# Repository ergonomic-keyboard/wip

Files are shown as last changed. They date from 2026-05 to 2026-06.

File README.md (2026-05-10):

# Custom Keyboard Generator

A browser-based tool for designing custom split ergonomic keyboards. Tap your finger positions, preview in 3D, and get a complete bill of materials with purchase links.

## Quick Start

Launch both the keyboard wizard and the requirement tracker:

```bash
cd /home/a/git/git/keyboard/wip
fuser -k 8080/tcp 8099/tcp 2>/dev/null; python3 -m http.server 8080 & node req-tracker.js & wait
```

- Keyboard wizard: http://localhost:8080/wizard.html
- Requirement tracker: http://localhost:8099

## Keyboard Wizard

Open http://localhost:8080/wizard.html and follow the 4 steps:

1. **Tap finger positions** — place your left hand flat and tap 3 key positions per finger column (pinky through thumb)
2. **3D preview** — interactive 3D model with shadows, wooden frame enclosure, click-to-press keys, exploded view, and component labels
3. **Bill of materials** — full parts list with prices and purchase links, download design files as a ZIP
4. **Firmware & test** — generated ZMK shield files, keymap visualization, native_posix hardware emulation tests

## Requirement Tracker

Tracks PASS/FAIL/SKIP status for each requirement in `final_requirements.md`, per git commit.

```bash
node req-tracker.js
```

Open http://localhost:8099.

**Features:**
- Each requirement from `final_requirements.md` is shown with its full text
- Mark each requirement PASS, FAIL, or SKIP
- Click the comment button to add notes (e.g. what's wrong, how to fix it)
- Edit requirement text inline (click the text, edit, click away to save)
- Add new requirements with the "+ Add requirement" button
- Navigate between git commits using the arrows in the top-right
- When navigating to a commit with no status, it inherits PASS/FAIL/SKIP from the nearest reviewed commit (comments are per-commit and not inherited)

**Storage:**
- Status files are saved in `req-status/<commit-hash>.json`
- These files are inside the git repo — commit them to sync progress to GitHub
- Requirement edits are saved directly to `final_requirements.md`

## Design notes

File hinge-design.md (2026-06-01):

# Hinge Mechanism Design — 6 Configurations

> Two fold hinges × three butterfly joints = six selectable configurations.

---

## 1. Architecture Overview

The hinge assembly sits at the center edge of the keyboard (X = hingeX, between R and T keys). It provides two independent rotation axes that intersect at a single **pivot center** point:

- **Fold axis (Y):** horizontal, runs belly-to-screen. Rotates halves 0°–180° (flat→closed) and beyond to 270° (tented).
- **Butterfly axis (Z):** vertical, perpendicular to table. Rotates each half ±45° (swimming-stroke wing motion).

### The Angled-Bracket Solution (from mechanism_1.png)

The pivot center must be raised above the board's top surface to allow clean 180° fold-to-close without the inner edges of the two halves colliding:

```
Board stack thickness: T_FRAME = 4.8mm (Z_BOTTOM=0 to Z_SWITCH_PLATE_TOP=4.8)

If pivot is AT the top surface (Z=4.8mm):
  The bottom edge (Z=0) of one half sweeps a 4.8mm arc.
  At 180°, the bottom edges collide — they occupy the same point.

Solution: Raise pivot by PIVOT_OFFSET above Z_SWITCH_PLATE_TOP.
  PIVOT_OFFSET = 4.0mm (provides ~3.2mm clearance at worst angle)
  Pivot center Z = Z_SWITCH_PLATE_TOP + PIVOT_OFFSET = 8.8mm

Each half connects to the pivot via an angled bracket:
  Bracket angle: α = 15° above horizontal
  Bracket arm length: L = PIVOT_OFFSET / sin(α) = 4.0 / 0.259 ≈ 15.5mm
  Horizontal reach: L × cos(α) = 15.5 × 0.966 ≈ 15.0mm

The bracket extends from the board's inner edge (X = hingeX) outward
by 15mm to reach the raised pivot. Each half has one bracket.
Total gap between halves when flat ≈ 30mm.
```

### Component Nesting Order (Z axis, bottom to top)

```
    Z = 14.8mm   ─ Thumb nut / cam lever (clamping the butterfly joint)
    Z = 13.0mm   ─ Belleville or wave washer
    Z = 12.5mm   ─ Upper butterfly disc (attached to RIGHT bracket)
    Z = 10.0mm   ─ ── teeth mesh zone ──
    Z =  9.5mm   ─ Lower butterfly disc (attached to LEFT bracket)
    Z =  8.8mm   ─ PIVOT CENTER ← fold shaft passes through here along Y
    Z =  8.0mm   ─ Fold hinge body (PHA housing or bearing yoke)
    Z =  4.8mm   ─ Z_SWITCH_PLATE_TOP (board top surface)
    Z =  0.0mm   ─ Z_BOTTOM (table)
```

The fold shaft (Y axis) passes through the central bore of both butterfly discs.
The butterfly discs rotate around Z relative to each other (constrained by teeth).
The fold shaft rotates around Y (constrained by the fold hinge mechanism).

---

## 2. Fold Hinge A: Reell PHA 8mm Friction Positioning Hinge

### Specifications

| Parameter | Value |
|---|---|
| Shaft diameter | 8mm |
| Weight | 8g |
| Torque | 0.46 N·m (recommended; range 0.28–0.65) |
| Rotation | 360° continuous |
| Life | 50,000 cycles |
| Mounting | M2.5 flag-leaf screw holes |
| Body dims (est.) | 22 × 12 × 10mm (L×W×H) |

### How It Works

A wrap-spring clutch around the 8mm shaft creates constant, symmetric friction torque. The shaft rotates freely in either direction against controlled resistance. No gears, detents, or discrete stops — infinite holding positions. The flag leaf (flat mounting tab) bolts to one bracket; the shaft end inserts into a bearing seat on the other bracket.

### 3D Parts List

| # | Part | Geometry | Material | Dims (mm) |
|---|---|---|---|---|
| 1 | PHA body | Rounded box | Zinc (chrome mat) | 22×12×10 |
| 2 | PHA shaft | Cylinder along Y | Steel | Ø8 × 30 |
| 3 | Flag leaf | Thin box, 2 screw holes | Steel | 15×12×1.5 |
| 4 | Left bracket | L-shape bent at 15° | Stainless steel | 15×12×2 arm |
| 5 | Right bracket | L-shape bent at 15° | Stainless steel | 15×12×2 arm |
| 6 | M2.5 bolts ×4 | Cylinder + hex head | Steel | Ø2.5×6 |

### Weight Breakdown

| Component | Weight |
|---|---|
| PHA 8mm hinge | 8g |
| Brackets (2× SS) | 10g |
| Fasteners (4× M2.5) | 2g |
| **Subtotal (fold only)** | **20g** |

---

## 3. Fold Hinge B: Miniature Sealed-Bearing Pivot

### Specifications

| Parameter | Value |
|---|---|
| Pivot pin diameter | 4mm |
| Bearing | 2× MR84ZZ (4×8×3mm, sealed) |
| Rotation | 270° (limited by yoke slot) |
| Friction | Near-zero (ball bearing) |
| Mounting | Yoke bolts to right bracket; pin retained by E-clips |

### How It Works

A titanium (or stainless) 4mm pin runs through two MR84ZZ micro ball bearings pressed into the arms of a U-shaped yoke. The yoke is bolted to one half's bracket. The pin is retained by E-clips and bolted to the other half's bracket. The yoke's open slot spans 270° of arc, allowing flat→tent→closed rotation. Nearly frictionless — tenting angle is held entirely by cables.

### 3D Parts List

| # | Part | Geometry | Material | Dims (mm) |
|---|---|---|---|---|
| 1 | Pivot pin | Cylinder along Y | Titanium | Ø4 × 18 |
| 2 | MR84ZZ bearings ×2 | Torus (OD8, ID4, W3) | Chrome steel | Ø8×3 |
| 3 | Yoke | U-bracket | Stainless steel | 12×20×2 sheet |
| 4 | E-clips ×2 | Thin ring | Spring steel | Ø4 |
| 5 | Left bracket | L-shape bent at 15° | Stainless steel | 15×12×2 |
| 6 | Right bracket | L-shape bent at 15° | Stainless steel | 15×12×2 |
| 7 | M2.5 bolts ×4 | Cylinder + hex head | Steel | Ø2.5×6 |

### Weight Breakdown

| Component | Weight |
|---|---|
| Pivot pin (Ti) | 0.6g |
| 2× MR84ZZ | 2.6g |
| Yoke (SS) | 4g |
| Brackets (2× SS) | 10g |
| E-clips + bolts | 2g |
| **Subtotal (fold only)** | **19g** |

---

## 4. Butterfly Joint 1: Hirth Coupling (24 teeth)

### Specifications

| Parameter | Value |
|---|---|
| Outer diameter | 20mm |
| Inner bore | 9mm (clears PHA 8mm shaft + gap) |
| Tooth count | 24 |
| Angular resolution | 15° per tooth |
| Tooth profile | 60° V-groove, radially swept |
| Tooth height at OD | 2.3mm |
| Tooth height at ID | 0.7mm |
| Disc thickness | 5mm (3mm teeth + 2mm base) |
| Material | Hardened tool steel (HRC 58) |
| Weight per disc | 8g |
| Clamping | M4 thumb nut + Belleville washer |

### Tooth Geometry (computed)

```
n = 24, α = 60°
K = tan(π/2/24) / tan(60°/2) = tan(7.5°) / tan(30°) = 0.1317 / 0.5774 = 0.228
β = arcsin(0.228) = 13.17° (flank angle)

Height at r = 10mm (OD/2): h = 2 × 10 × tan(β) = 20 × 0.234 = 4.68mm
  → This is peak-to-valley. Tooth height (one side) ≈ 2.3mm

Height at r = 4.5mm (ID/2): h = 2 × 4.5 × tan(β) = 9 × 0.234 = 2.1mm
  → Tooth height at bore ≈ 1.05mm

Pitch at OD: π × 20 / 24 = 2.62mm per tooth
```

### 3D Parts

| # | Part | Geometry | Material |
|---|---|---|---|
| 1 | Upper Hirth disc | Cylinder + radial V-teeth on bottom face | Tool steel |
| 2 | Lower Hirth disc | Cylinder + radial V-teeth on top face | Tool steel |
| 3 | M4 clamping bolt | Cylinder through center bore | Steel |
| 4 | Belleville washer | Conical annular disc | Spring steel |
| 5 | M4 thumb nut | Knurled cylinder | Brass |

### Weight: 16g (pair) + 3g (bolt/washer/nut) = **19g**

---

## 5. Butterfly Joint 2: Curvic Coupling (36 teeth)

### Specifications

| Parameter | Value |
|---|---|
| Outer diameter | 22mm |
| Inner bore | 9mm |
| Tooth count | 36 |
| Angular resolution | 10° per tooth |
| Tooth profile | Circular arc (concave/convex mating pair) |
| Tooth height at OD | 1.8mm |
| Disc thickness | 4.5mm (3mm teeth + 1.5mm base) |
| Material | 17-4PH stainless steel (case-hardened) |
| Weight per disc | 7g |
| Clamping | M4 thumb nut + Belleville washer |

### Key Difference from Hirth

Curvic teeth are ground with a circular arc profile. One disc has concave teeth, the other convex. This provides:
- Self-centering under axial load
- Higher contact area (line contact vs point contact)
- Better wear characteristics

### 3D Parts

Same assembly as BJ1 but with arc-shaped teeth instead of V-grooves.

### Weight: 14g (pair) + 3g (hardware) = **17g**

---

## 6. Butterfly Joint 3: Serrated-Face Flange (72 teeth)

### Specifications

| Parameter | Value |
|---|---|
| Outer diameter | 18mm |
| Inner bore | 9mm |
| Tooth count | 72 |
| Angular resolution | 5° per tooth |
| Tooth profile | Shallow triangular, 90° included angle |
| Serration depth | 0.5mm |
| Disc thickness | 2.5mm (0.5mm teeth + 2mm base) |
| Material | 7075-T6 aluminum, hard anodized |
| Weight per disc | 3g |
| Clamping | Cam lever (quarter-turn quick-lock) |

### Key Differences

- Shallowest teeth (0.5mm vs 2.3mm Hirth) — lightest and thinnest
- Finest angular resolution (5° vs 15° Hirth)
- Aluminum instead of steel — adequate for keyboard forces
- Cam lever instead of thumb nut — faster one-handed operation

### 3D Parts

| # | Part | Geometry | Material |
|---|---|---|---|
| 1 | Upper serrated disc | Thin cylinder + fine radial teeth | Aluminum |
| 2 | Lower serrated disc | Thin cylinder + fine radial teeth | Aluminum |
| 3 | Cam lever | L-shape with eccentric | Steel/aluminum |
| 4 | Wave washer | Wavy annular ring | Spring steel |
| 5 | M4 bolt | Through center bore | Steel |

### Weight: 6g (pair) + 4g (lever/washer/bolt) = **10g**

---

## 7. Six Configuration Summary

| Config ID | Fold Hinge | Butterfly Joint | Total Weight | Butterfly Resolution |
|---|---|---|---|---|
| `pha-hirth` | PHA 8mm friction | Hirth 24T | 20 + 19 = **39g** | 15° |
| `pha-curvic` | PHA 8mm friction | Curvic 36T | 20 + 17 = **37g** | 10° |
| `pha-serrated` | PHA 8mm friction | Serrated 72T | 20 + 10 = **30g** | 5° |
| `bearing-hirth` | Bearing pivot | Hirth 24T | 19 + 19 = **38g** | 15° |
| `bearing-curvic` | Bearing pivot | Curvic 36T | 19 + 17 = **36g** | 10° |
| `bearing-serrated` | Bearing pivot | Serrated 72T | 19 + 10 = **29g** | 5° |

All under 50g (F01.2). All metal (F01.1).

---

## 8. Mechanical Connection Detail

### How the fold hinge and butterfly joint physically connect

The fold shaft (PHA 8mm shaft or 4mm bearing pin) runs along the Y axis, passing through the central bore of both butterfly discs. The assembly stacks vertically:

```
CROSS-SECTION at pivot center (looking along Y axis):

         Z (up)
         │
    ┌────┴────┐ Thumb nut (M4, knurled brass)
    └────┬────┘
    ┌────┴────┐ Belleville washer (spring steel)
    └────┬────┘
    ╔════╧════╗
    ║ UPPER   ║ Butterfly disc — bolted to RIGHT bracket
    ║  DISC   ║ via 2× M2 ears extending beyond OD
    ║ ╲╱╲╱╲╱  ║ Teeth face DOWN
    ╠═════════╣ ← TEETH MESH PLANE (Z ≈ pivot center)
    ║ ╱╲╱╲╱╲  ║ Teeth face UP
    ║  DISC   ║ Butterfly disc — bolted to LEFT bracket
    ║ LOWER   ║ via 2× M2 ears extending beyond OD
    ╚════╤════╝
         │
    ═════●═════ ← Fold shaft/pin (along Y axis, into page)
         │       PHA body or bearing yoke sits here
    ┌────┴────┐
    │ FOLD    │ PHA body (Hinge A) or Yoke (Hinge B)
    │ HINGE   │
    └─────────┘
```

### Bracket-to-Board Attachment

```
SIDE VIEW (one half, looking along X axis):

    Board inner edge
         │
         ▼
    ┌────────────── board top Z=4.8 ──────────
    │ ┌──┐
    │ │M2│ bracket bolt #1
    │ │.5│
    │ └──┘   Bracket (2mm SS, bent at 15°)
    │    ╲
    │     ╲  15° angle
    │      ╲
    │       ╲
    │        ●──── pivot center Z=8.8
    │       ╱ ╲
    │      ╱   Butterfly disc ear (M2 bolts)
    │     ╱
    │ ┌──┐
    │ │M2│ bracket bolt #2
    │ │.5│
    │ └──┘
    │
    └────────────── board bottom Z=0 ──────────
```

### The M4 clamping system

A single M4 bolt runs vertically through the center bore of both butterfly discs, through the fold shaft (which has a cross-drilled hole for it), and threads into the thumb nut on top. The Belleville washer provides spring-loaded axial preload. When the thumb nut is tightened, the discs are squeezed together, engaging their teeth. When loosened, the discs can be rotated to a new butterfly angle.

For the serrated flange (BJ3), the M4 bolt + thumb nut is replaced by a cam lever mechanism for faster one-handed operation.

---

## 9. Fold Animation Mechanics

### Pivot Point Change

The current code uses `hingeZ = Z_SWITCH_PLATE_TOP` (4.8mm). The new design raises this:

```javascript
const PIVOT_OFFSET = 4.0; // mm above board top surface
const hingeZ = Z_SWITCH_PLATE_TOP + PIVOT_OFFSET; // = 8.8mm
```

This changes the fold pivot for `applyFold()` and `applyButterfly()`.

### Bracket Animation

When folding, the angled brackets rotate with their respective halves. The fold hinge body/yoke stays at the pivot center (it's the bearing/pivot — it doesn't move). The butterfly discs rotate with their respective brackets.

In the 3D render, each bracket and its attached butterfly disc should be parented to the appropriate half (leftHalf or rightHalf). The fold shaft/pin and hinge body stay at the center (parented to the hinge group, which doesn't fold).

### What Stays Fixed vs What Moves

| Part | Fold behavior | Parent |
|---|---|---|
| Fold shaft/pin | Stays at center | hingeGroup (center) |
| PHA body / yoke | Stays at center | hingeGroup (center) |
| Left bracket | Rotates with left half | leftHalf |
| Right bracket | Rotates with right half | rightHalf |
| Lower butterfly disc | Rotates with left half | leftHalf (via bracket) |
| Upper butterfly disc | Rotates with right half | rightHalf (via bracket) |
| Thumb nut | Rotates with right half | rightHalf |
| M4 bolt | Stays at center | hingeGroup (center) |

---

## 10. Implementation Plan

### hardware-catalog.js
- Replace all old hinge entries with 2 fold hinges + 3 butterfly joints
- Add `butterflyJoint` as a new selection category
- 6 valid combinations = foldHinge × butterflyJoint
- Each entry has dims, weight, bom, and rendering metadata

### hardware-builders.js
- Delete old `buildBarrelHinge`, `buildPianoHinge`, `buildBallJointHinge`
- New builders:
  - `buildPHAHinge(dims, mats)` — PHA body + shaft + flag leaf
  - `buildBearingPivot(dims, mats)` — yoke + pin + bearings + E-clips
  - `buildBracketPair(dims, mats)` — left + right angled brackets
  - `buildHirthDiscs(dims, mats)` — upper + lower Hirth discs with teeth
  - `buildCurvicDiscs(dims, mats)` — upper + lower Curvic discs with arc teeth
  - `buildSerratedDiscs(dims, mats)` — upper + lower serrated discs
  - `buildClampAssembly(type, dims, mats)` — thumb nut or cam lever + washer + bolt
- Master `buildHardwareAssembly()` updated to compose fold + butterfly + brackets + clamp

### render3d.js
- Update `hingeZ` to include PIVOT_OFFSET
- Bracket geometry added to leftHalf/rightHalf (moves with fold)
- Center hinge parts stay in hingeGroup
- `applyFold()` and `applyButterfly()` use new pivot Z
- No change to fold/butterfly quaternion math (already correct)

### wizard.html
- Add `hw-butterfly` dropdown alongside `hw-hinge`
- Event listener to rebuild hardware on butterfly joint change

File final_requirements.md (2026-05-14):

# Final Requirements — Split Keyboard

All requirements use **shall** language and are deterministic and verifiable unless placed in the **Design Guidelines** section at the end.

---
Y runs positiveley along the columns (top to bottom of keyboard). Z is vertical (up from the table). ?X runs from left to right?

## 0. Requirements Tracker

**REQ-T01** — The requirements progress page shall contain buttons for: PASS, Assumed Pass, SKIP, Comment (icon), and Delete (which turns into Undo after clicking it).

**REQ-T02** — The end of each requirement type section (e.g. "4. Hardware — Structure", "2. Validation") shall include a + button to append a new requirement in that section at the end.

**REQ-T03** — The requirements tracker shall keep the numbers/scores of the self-attempts, self fails, user corrections as 2 columns right of the Delete button column. If the user hovers over the user fail, it will expand the requirement to display the notes for that requirement. As soon as the user does not hover over that user-fail count anymore, the note will disapear. The user shall be able to togle the notes on or off per requirement, and with a single binary toggle above the user-fail column for all requirements.

---

## 1. Layout & Input

**REQ-L01** — The system shall use the passhutk ergogen website to capture finger tap positions and generate a JSON layout for the split keyboard.

**REQ-L02** — The system shall convert the computed switch positions from the passhutk JSON (per REQ-L10.2) into a `config.yaml` compatible with ergogen.xyz.

**REQ-L02.1** — The conversion shall use the computed switch positions and the fitting algorithm metadata, not the raw tap coordinates directly.
**REQ-L03a** — The fitting algorithm shall deterministically compute switch center positions (x, y in mm), rotations (degrees), and sizes (mm) from the raw tap coordinates, the calibrated PPM, and the selected fitting algorithm per column.

**REQ-L03a.1** — Given identical inputs (same taps, same PPM, same algorithm selection), the computed switch positions, rotations, and sizes shall be bit-identical.

**REQ-L03b** — The ergogen config.yaml, when processed by the ergogen engine, shall produce switch positions within 0.05 mm and rotations within 0.05 degrees compared to the computed switch positions from REQ-L03a.

**REQ-L03b.1** — The ergogen output shall produce matching switch-edge-sizes compared to the computed switch positions from REQ-L03a.

**REQ-L03b.2** — This tolerance (0.05 mm position, 0.05 degrees rotation) is the single source of truth for the taps-to-ergogen conversion fidelity.

**REQ-L04** — Each column (pinky, ring, middle, index, inner, and thumb) shall have exactly 3 keys.

**REQ-L04.1** — The user shall provide at least 3 finger taps per column.

**REQ-L04.2** — Additional taps beyond 3 are permitted and encouraged as they are used by the passhutk layout tool to determine the key switch positions.

**REQ-L04a** — The keyboard shall have 6 columns per half (pinky, ring, middle, index, inner, thumb) x 3 keys per column = 18 keys per half, 36 keys total.

**REQ-L04a.1** — The BOM quantities for switches, keycaps, and hot-swap sockets (where applicable) shall match this count.

**REQ-L05** — Within a single finger column, all key rectangles shall be projected onto the column axis (fitted line) and rotated so their edges are perpendicular to that line.

**REQ-L05.1** — Keys within a column shall not rotate relative to each other.

**REQ-L06** — The thumb cluster shall be the only zone permitted to have a separate splay/rotation angle independent of the matrix columns.

**REQ-L07** — The user shall select a thumb fitting mode from three options.

**REQ-L07.1** — STRAIGHT mode: The 3 thumb key centers shall be projected onto a best-fit regression line through the thumb taps, using the same CoG-based placement algorithm as matrix columns (REQ-SF03).

**REQ-L07.1a** — In STRAIGHT mode, all 3 thumb keys shall share one rotation angle (the line angle).

**REQ-L07.1b** — STRAIGHT mode shall always produce a valid ergogen config.yaml (splay=0, spread=inter-key distance along line).

**REQ-L07.2** — ROTATED mode: The 3 thumb key centers shall be placed on a circular arc.

**REQ-L07.2a** — In ROTATED mode, the user shall specify (or the system shall fit from taps) a center point and radius R.

**REQ-L07.2b** — In ROTATED mode, keys shall be spaced at angular intervals on the arc.

**REQ-L07.2c** — In ROTATED mode, each key's rotation shall be tangent to the arc.

**REQ-L07.2d** — ROTATED mode shall always produce a valid ergogen config.yaml (uniform splay per column, inverse-solved origin offsets).

**REQ-L07.3** — ERGOGEN mode: The user shall directly enter ergogen thumb zone parameters (key.spread, key.splay, key.origin per column).

**REQ-L07.3a** — In ERGOGEN mode, these values shall be passed through to the config.yaml verbatim.

**REQ-L07a** — The selected thumb mode and its parameters shall be stored in the export JSON (per REQ-L10).

**REQ-L07a.1** — For STRAIGHT: the line angle shall be stored.

**REQ-L07a.2** — For ROTATED: the center, radius, and angular offsets shall be stored.

**REQ-L07a.3** — For ERGOGEN: the raw ergogen params shall be stored.

**REQ-L07b** — When the user switches thumb mode, the stage 1 canvas shall immediately recompute and redraw the 3 thumb switch positions using the newly selected algorithm.

**REQ-L07b.1** — The previous thumb taps shall be preserved (not cleared) when switching thumb mode.

**REQ-L08** — The system shall provide a "Tune Scale" calibration function: a modal displaying a reference line, user entry of measured physical width in mm, computing px/mm from CSS pixel width / entered mm.

**REQ-L08.1** — The calibrated value shall persist across sessions via localStorage.

**REQ-L09** — The ergopadToErgogen converter shall produce ergogen config parameters (spread, stagger, splay, padding, origin).

**REQ-L09.1** — The produced parameters, when processed by ergogen's placement algorithm, shall reconstruct the computed switch positions from REQ-L03a within the tolerance of REQ-L03b.

**REQ-L09.2** — The converter shall simulate ergogen's cumulative rotation stack.

**REQ-L09.3** — The converter shall inverse-solve for world-space zone_anchor positions.

**REQ-L09.4** — For the thumb zone, the converter shall use the algorithm-specific parameter derivation corresponding to the selected thumb mode (REQ-L07).
**REQ-L10** — The user shall be able to export and reload layout data as JSON.

**REQ-L10.1** — The export shall include raw tap coordinates per column (as `{x, y}` arrays).

**REQ-L10.2** — The export shall include computed switch positions per key: center (x, y) in mm, rotation in degrees, and switch size (width, height) in mm.

**REQ-L10.3** — The export shall include the fitting algorithm used per column: `regression-line` for matrix columns; `STRAIGHT`, `ROTATED`, or `ERGOGEN` for the thumb column, plus the algorithm-specific parameters (per REQ-L07a).

**REQ-L10.4** — The export shall include `calibratedPPM`, `canvasWidth`, `canvasHeight`.

**REQ-L10.5** — Loading shall scale raw tap positions correctly if canvas dimensions differ from the original.

**REQ-L10.6** — After loading, the system shall recompute switch positions from the stored taps and algorithm, and verify they match the stored computed positions (within floating-point tolerance).

**REQ-L11** — In the first screen where the finger taps are added the user shall be able to zoom in and out the key switches using 2 keyboard buttons/shortcuts that do not interfere with the normal browser/rest of the website.

**REQ-L11.1** — The scale tuning number shall change on a 1:1 ratio with the zoomlevel if it was specified earlier.

---

## 2. Validation

**REQ-V01a** — (Boundary 1 — taps to computed switches) The system shall verify that the fitting algorithm (per REQ-L03a) produces deterministic switch positions from the stored raw taps.

**REQ-V01a.1** — On JSON reload, the recomputed switch positions shall match the stored computed positions within floating-point tolerance (< 1e-6 mm).

**REQ-V01a.2** — If they differ, the system shall flag a fitting algorithm inconsistency error.

**REQ-V01b** — (Boundary 2 — computed switches to ergogen output) For each key, the distance between the computed switch position (from REQ-L03a) and the ergogen-generated position (from the config.yaml processed by ergogen) shall be less than the tolerance defined in REQ-L03b (0.05 mm).

**REQ-V01b.1** — Rotation shall match within 0.05 degrees.

**REQ-V01b.2** — If exceeded, the system shall flag the specific key with its position and rotation delta and throw an error.

**REQ-V02** — The relative arrangement of keys (center-to-center distances and directions between adjacent keys) shall be preserved between the computed switch positions and the ergogen output.

**REQ-V02.1** — The system shall detect if ergogen reorders, collapses, or distorts spatial relationships.

**REQ-V03** — No two switches shall occupy the same position.

**REQ-V03.1** — The center-to-center distance between every pair of keys shall exceed the switch housing width.

**REQ-V03.2** — This check shall apply both within each column and across columns.

**REQ-V04** — Validation shall recompute every time a finger tap is added or removed, without requiring navigation to a separate page.

**REQ-V05** — Validation errors shall be displayed directly on the page 1 canvas, overlaid on the affected key positions, using color-coded indicators (red for invalid, green for valid).

**REQ-V05.1** — A human-readable summary message shall be displayed below the toolbar.

**REQ-V06** — If validation detects overlapping switches or position mismatches exceeding the threshold, the Next button to page 2 shall be disabled.

**REQ-V06.1** — The error shall be displayed prominently.

---

## 3. Hardware — Switches & Keys

**REQ-H01** — The keyboard shall use Cherry MX ULP switches (ref: keeb.supply/products/cherry-mx-ulp).

**REQ-H02** — Soldering shall not be required for keyboard assembly, with the sole exception of Cherry MX ULP switches, which are SMD-mount and require soldering to the PCB.

**REQ-H02.1** — All other electrical connections (MCU, battery connector, USB-C) shall use solderless methods (hot-swap sockets, press-fit, pin headers, or similar).

**REQ-H03** — Each keycap in the 3D render and final product shall display the selected keyboard layout, e.g. QWERTY or Dvorak letter or symbol (Space, Tab, Backspace, Enter, etc.).

**REQ-H03.1** — A keycap legend set or sticker overlay sheet shall be included in the BOM.

---

## 4. Hardware — Structure

**REQ-S01** — The keyboard shall consist of two separate, independent halves.

**REQ-S02** — The board outline shall be smoothed from the raw ergogen staircase output.

**REQ-S02.1** — Index finger side: straight edge.

**REQ-S02.2** — Top edge: arc with radius determined by the angle between index and pinky columns.

**REQ-S02.3** — Pinky side: straight edge.

**REQ-S02.4** — Bottom edge: smaller arc.

**REQ-S02.5** — Thumb cluster: 8-12 mm fillet/border around thumb keys.

**REQ-S02.6** — Perimeter fillet shall be at least 8 mm.

**REQ-S03** — The board outline, switch plate, and wooden frame shall extend to cover all thumb keys.

**REQ-S03.1** — The thumb cluster shall not be a floating island; it shall be structurally connected to the main matrix area.

**REQ-S04** — The frame material shall be 2 mm thick bamboo plywood (Z-axis material thickness).

**REQ-S04.1** — The frame shall be two-part milled construction (bottom backbone + top bezel).

**REQ-S05** — The frame wall width (XY-plane border around the PCB/plate) shall be at least 4 mm.

**REQ-S06** — Fasteners shall be M2 heat-set brass threaded inserts (pressed into the frame from the bottom) paired with M2 countersunk flat-head bolts from the top.

**REQ-S06.1** — Bolt heads shall sit flush with the surface.

**REQ-S07** — Each half shall have at least 5 mounting points placed according to REQ-S07.1 through REQ-S07.5. The positions below in S07.1 to S07.5 are described for the left half, these nut and bolt coordinates are to be mirrored to the right half (acrross the middle axis from the user belly to the screen).
**REQ-S07.1** — Looking at the keyboard from the user, at the left half, with closest to the user as "bottom" and closest to screen as "top". One mounting point **on the diagnonal switch line (outside switch) through the top-left corner of the Y key, with the center of the nut on the diagonal of the switch**.  The bolt center shall be ≤ 10 mm from that corner. The bolt shall not overlap any switch footprint.
**REQ-S07.2** — Looking at the keyboard from the user, at the left half, with closest to the user as "bottom" and closest to screen as "top".  One mounting point **on the diagonal line (outside switch) through bottom-left corner of the N key**. The bolt center shall be ≤ 10 mm from that corner.
**REQ-S07.3** — Looking at the keyboard from the user, at the left half, with closest to the user as "bottom" and closest to screen as "top".  One mounting point bolt shall be on the **key diagonal line  (outside switch) through the top right corner of P switch** The bolt center shall be ≤ 10 mm from that corner.
**REQ-S07.4** — Looking at the keyboard from the user, at the left half, with closest to the user as "bottom" and closest to screen as "top". One mounting point bolt shall be on the **key diagonal line (outside switch) through the top-right corner of the outermost thumb key** (the thumb key farthest from the center/hinge). The bolt center shall be ≤ 10 mm from that corner.
**REQ-S07.5** — Looking at the keyboard from the user, at the left half, with closest to the user as "bottom" and closest to screen as "top". One mounting point bolt shall be on the **key diagonal line (outside switch) through the bottom-right corner of the outermost thumb key** (the thumb key farthest from the center/hinge). The bolt center shall be ≤ 10 mm from that corner.
**REQ-S07a** — Each mounting bolt shall pass through the top frame bezel and clamp through all intermediate layers (switch plate, cork, PCB, cork) into a heat-set brass insert in the bottom frame backbone.

**REQ-S07a.1** — All intermediate layers (switch plate, cork gaskets, PCB, bottom plate) shall have clearance holes at each mounting point.

**REQ-S07a.2** — The bolt-insert joint shall sandwich the full stack between the two frame pieces.

**REQ-S08** — The base layer stack (excluding cork gaskets, frame bezel, and keycaps) shall be: Bottom plate (bamboo) 2.0 mm (per REQ-S04), PCB (FR-4) 0.8 mm (standard 2-layer), Switch plate (bamboo or FR-4) 1.0 mm. Base total: 3.8 mm.

**REQ-S08.1** — The actual layer thicknesses shall be verified against the Cherry ULP switch datasheet and nice!nano PCB clearance requirements.

**REQ-S08.2** — If the datasheet requires different thicknesses, these values shall be updated and REQ-S09 recalculated accordingly.

**REQ-S08a** — A 0.5 mm natural cork gasket sheet shall be placed between the bottom plate and PCB, and between the PCB and switch plate.

**REQ-S08a.1** — Total stack height increase from cork shall be 1.0 mm.

**REQ-S09** — The overall keyboard thickness shall be minimized within the requirement-compliant design space.

**REQ-S09.1** — The total stack height shall not exceed 4.8 mm (3.8 mm base per REQ-S08 + 1.0 mm cork per REQ-S08a), excluding the frame bezel and keycaps.

**REQ-S10** — A battery area shall be designated on the PCB (under/beside the MCU, or along the thumb padding space in slender form factors).

**REQ-S10.1** — The design shall accommodate the battery without increasing the overall board width beyond what is required by the key layout.

**REQ-S10.2** — If the battery exceeds the available stack clearance, the bottom plate shall be locally milled thinner (cutout/recess) at the battery location to house it within the REQ-S09 stack height.

**REQ-S11** — A battery connector footprint shall be present on the PCB.

**REQ-S11.1** — Physical clearance shall be verified (bottom plate cutout or recess if needed).

**REQ-S12** — The key positions and cutout locations in the switch plate shall use expanded key padding (`px + 4` for board outline, `px + 8` for frame) to produce a smooth, continuous perimeter around all keys including the thumb cluster.

---

## 5. Hardware — Hinge & Folding

**REQ-F01** — The folding mechanism shall connect the two halves at the center (approximately between the R and T key positions).

**REQ-F01.1** — It shall be made of metal.

**REQ-F01.2** — It shall weigh at most 50 grams total.

**REQ-F01a** — The mechanism shall support two independent rotation axes.

**REQ-F01a.1** — Fold axis (horizontal, running from user belly toward screen): The two halves shall fold from flat on the table (0 degrees) to fully tented (at most 90 degrees).

**REQ-F01a.2** — Butterfly axis (vertical, perpendicular to the table surface): When flat on the table, the two halves shall rotate forward and backward like wings (toward/away from the screen) up to approximately 45 degrees from the centerline.

**REQ-F01b** — The butterfly rotation range (up to ~45 degrees) may be limited at certain fold angles due to geometric constraints (e.g., thumb pads colliding).

**REQ-F01b.1** — The 3D render shall enforce these collision limits per REQ-R07.

**REQ-F01c** — The keyboard shall fold fully closed for transport.

**REQ-F01c.1** — When folded closed, the keycap surfaces shall face each other (inward fold).

**REQ-F01c.2** — If a single mechanism cannot provide both the fold/butterfly range (REQ-F01a) and fold-to-close, the two connecting poles to the hinge shall be disconnectable (e.g., via magnetic breakaway or quick-release).

**REQ-F01c.3** — In that case, 2 or 3 magnets embedded in the keyboard wood frame shall hold the two halves closed.

**REQ-F01d** — The tenting angle shall be primarily determined and held by the cable turnbuckle settings (REQ-F09).

**REQ-F01d.1** — The hinge may optionally include a friction lock or thumb nut for additional rigidity on uneven/unstable surfaces.

**REQ-F01d.2** — If included, it shall not be required for normal desk use.

**REQ-F05** — Two horizontal cables shall connect the two halves of the keyboard on the bottom plate of the keyboard: one across the top row (approximately Q to P), one across the bottom row (approximately Z to M).

**REQ-F05.1** — These cables shall prevent the keyboard from collapsing under gravity/key press force.

**REQ-F05.2** — The cable closest to the user shall be attached below the left half of the keyboard board at the coordinate of the bottom right corner of the N switch.
**REQ-F05.3** — The cable closest to the user shall be attached below the right half of the keyboard at the coordinate of the bottom left corner of the Z switch.

**REQ-F05.4** — The cable furthest away from the user shall be attached below the left half of the keyboard board at the coordinate of the bottom right corner of the Y switch.

**REQ-F05.5** — The cable furthest away from the user shall be attached below the left half of the keyboard board at the coordinate of the bottom left corner of the Q switch.

**REQ-F05.6** — The cables will be attached on the left side using a nut with a ring eye as had through which the cable will pass. its bolt will be sinked into the cork and wooden backplate.

**REQ-F05.7** — The cables will be attached on the right side of the keyboard using magnetic attachment that clicks into place by moving the two sides close into each other like two hooks grappling into each other, such that the tension on the cable is transferred through the hook contacts, but that the  hooks staying hooked into each other is done by the magnet. (a cone and cone hole would prevent side slipping in any direction, a magnet would prevent disconnect at random wiggling/slight moments of movement where the tension on the cable may be reduced.
Alternatively Cables shall use quick-release clevis pins with spring-loaded ball detent for one-handed press-button detach. In that case Clevis brackets shall be recessed into the frame edge.
**REQ-F07** — The quick-release clevis pins with spring-loaded ball detent shall be positioned such that when the keyboard is folded closed, it will be on a flat surface on the backside of the board, and not at the edge of the keyboard.

**REQ-F08** — When detached, the cables shall wrap around the closed keyboard to keep it shut (like a rope around a diary).

**REQ-F08.1** — Two elastic bands shall secure the cables around the closed keyboard regardless of turnbuckle position, so the user does not need to adjust turnbuckle length each time the keyboard is folded.

**REQ-F09** — The cables shall include turnbuckles for adjustable tension/length, which controls the tenting angle and the butterfly wing rotation around the vertical axis.

---

## 6. Electronics & Connectivity

**REQ-E01** — The keyboard shall use the nice!nano wireless MCU.

**REQ-E02** — The keyboard shall support the following connectivity modes.

**REQ-E02.1** — Both halves communicate with each other over Bluetooth. One half connects to the laptop via USB-C; the other half syncs wirelessly to the first.

**REQ-E02.2** — Both halves connected directly to a laptop via USB-C (each half operates as an independent USB HID device).

**REQ-E02.3** — Fully wireless operation over Bluetooth (both halves to laptop, half-to-half over Bluetooth).

**REQ-E02.4** — In wired modes, Bluetooth shall be completely disableable via firmware configuration.

**REQ-E02.5** — Half-to-half communication shall use Bluetooth (not wired USB-C between halves). A non-wireless MCU option is out of scope.

**REQ-E03** — Each half shall have one USB-C port for charging and/or data.

**REQ-E04** — Two 301230 LiPo batteries (one per half) shall be included in the BOM.

**REQ-E04.1** — Battery placement shall be visible in assembly.scad.

**REQ-E04.2** — The battery connection to the PC will be included in the rendering.

**REQ-E05** — Keyboard firmware shall be available and functional for the nice!nano MCU (e.g., ZMK or equivalent).

---

## 7. Bill of Materials & Sourcing

**REQ-B01** — A complete Bill of Materials shall be produced, listing every component required to build the keyboard.

**REQ-B02** — Each BOM item shall include a link to an online supplier and the price per element.

**REQ-B03** — The BOM shall include the following components:

**REQ-B03.1** — Cork gasket sheets.

**REQ-B03.2** — Bamboo plywood sheets.

**REQ-B03.3** — M2 heat-set brass inserts.

**REQ-B03.4** — M2 countersunk flat-head bolts.

**REQ-B03.5** — Quick-release clevis pins.

**REQ-B03.6** — Turnbuckle cable assemblies.

**REQ-B03.7** — Elastic bands.

**REQ-B03.8** — Hinge mechanism (metal).

**REQ-B03.9** — Magnets for hinge pole disconnect and/or frame closure (per REQ-F01c).

**REQ-B03.10** — Cherry ULP switches.

**REQ-B03.11** — Keycaps (with legends or sticker sheet).

**REQ-B03.12** — nice!nano MCUs.

**REQ-B03.13** — 301230 LiPo batteries.

**REQ-B03.14** — USB-C connectors.

---

## 8. Assembly

**REQ-A01** — All bolts and inserts required for assembly shall be specified in the BOM with their positions documented.

**REQ-A01.1** — No screws shall be used; the design shall use only M2 bolts with heat-set brass inserts (per REQ-S06).

**REQ-A01.2** — There will be one nut and bolt in the bottom left corner, with the outer edge of the bolt 0.5 cm out of the edge (so the center of the nut will be 0.5 cm + nutradius from the edge). The nut will nut be at the position of a switch (again 0.5 cm away from switch.)
There will be another nut left above the thumb (as low as possible but still above.

If the angle between the inner column and the thumb column is larger than 10 degrees, then there will be another nut left below the outer inner colum. Otherwise it will be above the outer most switch of the inner column (between the switch and the edge).

Another screw will be in the top right corner.
Another screw will be in the bottom left corner.
**REQ-A02** — Files required for CNC-cutting/laser-cutting the wood frame pieces shall be generated and included in the project output.

**REQ-A03** — A builder's guide (`grandma_builder.md`) shall be produced containing only the sequential steps required for a non-technical person to assemble the keyboard from the kit.

---

## 9. 3D Render & Visualization

**REQ-R01** — The system shall produce an interactive 3D viewer (not just static PNG renders).

**REQ-R01.1** — The user shall be able to orbit, zoom, and pan.

**REQ-R01.2** — The user shall see a small legend with the keyboard navigation shortcuts in the top right of the screen.

**REQ-R01.3** — Ensure if the user wants to see component labels that it uses the diagonal line to top right followed by horizontal line towards its label, if the render is moved, resort the labels to prevent line crossings. Allow togling them off, e.g. if nuts are 7 nuts, show 7 labels, but allow one to toglle off specific nut lable,s or just the group nut.

**REQ-R02** — The 3D model shall update automatically when the input config changes (i.e., `generate.sh` produces a viewable 3D file).

**REQ-R03** — The 3D model shall show all components listed in REQ-R03.1–R03.12.

**REQ-R03.1** — The 3D model shall render the bamboo bottom plate.

**REQ-R03.2** — The 3D model shall render the cork gaskets.

**REQ-R03.3** — The 3D model shall render the FR-4 PCB.

**REQ-R03.4** — The 3D model shall render the switch plate.

**REQ-R03.5** — The 3D model shall render the wooden frame surround.

**REQ-R03.6** — The 3D model shall render the keycaps.

**REQ-R03.7** — The 3D model shall render the nice!nano MCU.

**REQ-R03.8** — The 3D model shall render the USB-C ports.

**REQ-R03.9** — The 3D model shall render the batteries.

**REQ-R03.10** — The 3D model shall render the hinge.

**REQ-R03.11** — The 3D model shall render the cables.

**REQ-R03.12** — The 3D model shall render the fasteners.

**REQ-R04** — An exploded view shall be togglable.

**REQ-R04.1** — In exploded view, all layers (bottom plate, cork, PCB, switch plate, frame) shall be distinguishable by material and labeled.

**REQ-R05** — Keycaps shall respond to click with a press animation.

**REQ-R06** — The center joint/hinge shall visually articulate when the fold angle changes.

**REQ-R06.1** — All hinge sub-components shall rotate/translate to match the fold angle.

**REQ-R06.2** — The specific sub-components rendered shall match the final hinge mechanism selected per REQ-F01.

**REQ-R07** — The butterfly wing rotation slider shall be available and its range shall be restricted by not allowing overlap/collision between any components (of the 2 sides, nor folding mechanism) depending on the fold slider setting.

**REQ-R07.1** — The fold slider shall always have full range.

**REQ-R07.2** — If a fold angle is selected at which the butterfly wing rotation slider constraints are violated, the butterfly wing rotation slider shall return to the nearest valid constrained (maximum) angle in degrees.

**REQ-R08** — The 3D render shall provide a fold slider covering the full range from flat (0 degrees) through tented (up to 90 degrees) through to fully closed (180 degrees).

**REQ-R08.1** — If the hinge mechanism requires disconnection to fold closed (per REQ-F01c), the render shall animate the disconnect (poles separating, magnets engaging) at the appropriate angle.

**REQ-R08.2** — Both halves shall remain fully visible and correctly positioned at all angles.

**REQ-R08.3** — No half shall disappear, clip through the ground plane, or produce visual artifacts.

**REQ-R08.4** — The pivot point shall be the hinge center axis.

**REQ-R09** — Cables shall visually connect to their keyboard edge attachment points.

**REQ-R09.1** — When folding, cables shall animate their release at the quick-release clevis pins and wrap around the other side.

**REQ-R10** — The nice!nano USB-C ports shall be rendered as chrome/metallic connectors with a dark opening, identifiable as USB-C at a glance.

**REQ-R11** — Keycap and switch positions in the 3D render shall be exactly aligned with switch plate cutouts.

**REQ-R11.1** — The coordinate offset shall be computed from the config.yaml directly, not from any generated svgs.

**REQ-R12** — Key legends shall be rendered as flat plane meshes on top of keycaps using canvas textures, with correct rotation matching key orientation.

**REQ-R13** — The bamboo/wood material shall use a pronounced normal map for surface relief and appropriate roughness/metalness PBR values.

**REQ-R13.1** — Visible grain lines, growth rings, node bands, tonal variation, and fiber detail shall be present.

**REQ-R14** — Fold direction in the 3D render shall match REQ-F01c (inward fold, keycap surfaces face each other when folded).

**REQ-R15** — No render clipping shall occur during fold at any angle.

**REQ-R15.1** — Clipping planes shall rotate with their respective halves.

**REQ-R16** — The 3D render shall visually reflect REQ-S03: the thumb cluster shall appear connected to the main body in all views (not as a floating island).

**REQ-R17** — You shall show the key switch outlines from the 1.Finger Positions as the highest layer in purple at 3 mm above the highest point of the board. (Don't edit them or anything, just a raw coordinate and rotational copy paste).

**REQ-R18** — You shall show the angle in degrees between the inner column line and the thumb column line in case the Thumb STRAIGHT option is shown. Also in purple (with a circular arrow between the two lines.)

**REQ-R19** — You shall render the board from a point of view like the user sees it when the user starts typing, so left is the left thumb pad (the left hand is also entered in stage 1 Figure Positions with the pinky column left and the left thumb in the BOTTOM right). So the thumbs are closer to the user than the other columns (NOT FURTHER AWAY).

**REQ-R20** — The render shall show the full fold to 0 degrees to 180 degrees flat on the table, to 270 degrees tilted.

**REQ-R21** — The render shall show the full fold to 0 degrees to 45 degrees butterfly as optional.

**REQ-R21.1** — You shall limit that degree based on the two halves bump into each other constraint at any given integer folding angle.

**REQ-R21.2** — The butterfly folds forward, away from user, toward screen. (horizontal line/as it is now is the normal/0 degrees.)

**REQ-R21.3** — In the GUI clearly indicate the limitation based on the fold angle if there is any limitation.

**REQ-R22** — ~~SUPERSEDED by REQ-R30.~~ *(Original: MCU on PCB top surface at half center.)*

**REQ-R23** — ~~SUPERSEDED by REQ-R33, REQ-R36.~~ *(Original: Battery between bottom plate and PCB with recess.)*

**REQ-R24** — ~~SUPERSEDED by REQ-R32, REQ-R34.~~ *(Original: USB-C at outer board edge as separate component.)*

**REQ-R25** — ~~SUPERSEDED by REQ-R30, REQ-R31, REQ-R32.~~ *(Original: Positions computed from bbox.)*

**REQ-R26** — The 3D render shall provide individual binary visibility toggles for each hardware layer.

**REQ-R26.1** — Keycaps toggle: Keycap meshes + key legends, default ON.

**REQ-R26.2** — Switch Plate toggle: Switch plate + switch housings/stems, default ON.

**REQ-R26.3** — Cork Upper toggle: Upper cork gasket, default ON.

**REQ-R26.4** — PCB toggle: PCB + MCU + USB-C + diodes + solder pads, default ON.

**REQ-R26.5** — Cork Lower toggle: Lower cork gasket + battery, default ON.

**REQ-R26.6** — Bottom Plate toggle: Bottom plate + battery recess, default ON.

**REQ-R26.7** — Each toggle shall independently show/hide that layer's meshes without affecting any other layer.

**REQ-R27** — Layer toggles shall work in both normal (assembled) view and exploded view.

**REQ-R27.1** — Toggling a layer off shall hide its meshes in whichever view mode is active.

**REQ-R27.2** — The exploded view separation and the layer toggles shall be independent controls.

**REQ-R28** — When a layer is toggled off, its exploded-view label (if any) shall also be hidden.

**REQ-R28.1** — Toggling the layer back on shall restore the label (if exploded view labels are enabled).

**REQ-R29** — The layer toggle controls shall be rendered as a row of labeled checkboxes (all checked by default), positioned near the existing fold/butterfly sliders in the 3D view toolbar.

**REQ-R29.1** — Each checkbox shall be labeled with its layer name.

**REQ-R30** — The nice!nano MCU shall be mounted on the underside of the PCB (components facing downward, toward the bottom plate).

**REQ-R30.1** — Its Z position shall place the MCU PCB flush against the underside of the main PCB at `Z_PCB`.

**REQ-R30.2** — The MCU's tallest component (USB-C connector, ~3.26mm) faces downward into a milled pocket in the bottom plate.

**REQ-R30.3** — The ergogen config shall include a back-side (`B.Cu`) footprint for the nice!nano, or the KiCad PCB file shall be post-processed to flip the MCU footprint to the back copper layer.

**REQ-R31** — The nice!nano shall be positioned so that its outer edge (the edge furthest from the hinge) aligns with the inside edge of the innermost pinky column key positions (colIdx 0).

**REQ-R31.1** — The MCU body extends from that edge inward (toward the hinge).

**REQ-R31.2** — The MCU is then rotated around the USB-C port position to match the local board edge angle (per REQ-R32).

**REQ-R31.3** — This ensures the MCU does not overlap with optional structures that may be added to the board perimeter (rubber feet, edge bolts, fillet radius).

**REQ-R32** — The nice!nano shall be positioned and rotated so that its USB-C port is flush with the nearest board outline edge (not protruding beyond it).

**REQ-R32.1** — The MCU shall be rotated to match the angle of the local board edge segment so the USB-C opening faces outward perpendicular to the edge.

**REQ-R32.2** — The frame shall have a rectangular cutout (milled slot) at the USB-C port location, aligned with the edge angle, sized to allow cable insertion.

**REQ-R32.3** — The USB-C connector face shall be coplanar with the outer frame surface.

**REQ-R32.4** — The slot shall be visible in the 3D render.

**REQ-R33** — The bottom plate shall have a milled pocket (recess) at the MCU location, deep enough to house the MCU body (1.6mm) plus its tallest downward-facing component (USB-C connector, ~3.26mm).

**REQ-R33.1** — The cork lower gasket shall have a matching cutout at the MCU location.

**REQ-R33.2** — The pocket shall be visible in the 3D render as a distinct recessed area in the bottom plate.

**REQ-R34** — The USB-C connector shall remain physically part of the nice!nano MCU mesh (not a separate component).

**REQ-R34.1** — It sits at the MCU's short edge closest to the board outline.

**REQ-R34.2** — Because the MCU is rotated to match the board edge angle (per REQ-R32), the USB-C opening naturally faces outward perpendicular to the edge and is accessible from outside the keyboard through the frame slot.

**REQ-R34.3** — The separate `createUsbCPort()` function shall be removed.

**REQ-R35** — The ergogen pipeline shall generate a post-processing script (in `generate.sh`) that flips the nice!nano footprint from `F.Cu` to `B.Cu` in the output `.kicad_pcb` file, preserving full automation of the PCB generation.

**REQ-R36** — The battery shall be positioned adjacent to the nice!nano MCU in the same under-PCB cavity, sharing the bottom plate milled pocket.

**REQ-R36.1** — The battery and MCU shall not overlap.

**REQ-R36.2** — Both shall fit within the board outline.

**REQ-R37** — The 3D render shall include a toggleable XYZ coordinate system indicator showing the model-space axes.

**REQ-R37.1** — Red = X axis (toward hinge), Green = Y axis (along columns), Blue = Z axis (up from table).

**REQ-R37.2** — Tick marks shall be placed at 10mm intervals with larger ticks at 100mm.

**REQ-R37.3** — Named spatial anchors (`bbox.min.x`, `hingeX`, `halfCenterX`, `bbox.min.y`, `bbox.max.y`, `center`) shall be marked with orange diamond markers and labels at their positions on the board.

**REQ-R37.4** — The indicator shall be toggled via an "Axes" checkbox in the toolbar, unchecked by default.

**REQ-R37.5** — The coordinate system and named anchors shall be documented in `wip/geometry.md`.

**REQ-R38** — The axis indicator origin shall be positioned at the top key of the pinky column (colIdx 0, minimum Y in model space) at the switch plate surface (Z_SWITCH_PLATE_TOP).

**REQ-R38.1** — This places the origin at the top-left switch as seen on screen.

**REQ-R38.2** — The origin label shall display the model-space coordinates of this position.

**REQ-R39** — The angle of the USB-C port (and thus the rotation of the nice!nano MCU) shall be determined by sampling the board outline at two points: the left edge and the right edge of the USB-C port opening.

**REQ-R39.1** — The angle is computed as `atan2(dy, dx)` between these two sampled points.

**REQ-R39.2** — This method works regardless of whether the local board edge is a straight line, a fillet arc, or any other curve — it produces the correct tangent angle at the USB-C port width scale.

**REQ-R39.3** — The MCU shall be rotated by this angle so the USB-C face is parallel to the local edge at those two points.

---

## 10. Stage Fidelity

**REQ-SF01** — The computed switch positions and orientations stored in the export JSON (per REQ-L10.2) shall be reproduced in the ergogen output and 3D render within the tolerance defined in REQ-L03b (0.05 mm position, 0.05 degrees rotation) for all keys in all columns, including the thumb column regardless of thumb mode.

**REQ-SF01.1** — Per-row padding shall match stage 1's center-of-gravity-based asymmetric placement.

**REQ-SF01.2** — This requirement is verified by REQ-V01b.

**REQ-SF02** — Switch rectangles drawn on the page 1 canvas shall have their edges perpendicular to the column regression line.

**REQ-SF02.1** — The rotation angle shall be `PI/2 + atan(slope)` applied via `ctx.rotate(-rad)` in canvas coordinates.

**REQ-SF03** — Adding more finger taps to a column shall spread the 3 switch positions outward naturally using center-of-gravity of upper/lower halves of projected taps.

**REQ-SF03.1** — The stage 1 drawCanvas algorithm shall not be modified.

---

## Design Guidelines (Subjective / Non-Verifiable)

These are aesthetic and experiential goals that guide design decisions but are not pass/fail verifiable. They may be taken into consideration after all other requirements are met, and taken into account where it does not lead to incredible challenges during the process of generating requirement compliance.

**DG-01** — The board outline should feel like a single deliberate shape, not an artifact of the layout tool.

**DG-02** — The overall rendering should look like a professional product visualization: soft shadows, PBR materials with correct roughness/metalness, anti-aliased edges, subtle environment reflections on metallic parts, ACES filmic tone mapping.

**DG-03** — The bamboo material should be recognizable as bamboo/wood at a glance, not bland plastic.

**DG-04** — After all functional requirements are met, a design pass should refine the overall shape: smooth every edge, add intentional asymmetry where it serves ergonomics, and ensure the silhouette reads as a single coherent form.

**DG-05** — The overall thickness should be kept as thin as possible while meeting structural and acoustic requirements.

**DG-06** — The cable quick-release mechanism should require zero thought to operate in daily use.

**DG-07** — The keyboard when folded should form a compact, non-colliding package.

**DG-08** — The typing acoustics should be dampened and pleasant, not hollow or rattling.

**DG-09** — The frame should look like a natural material (bamboo), not like a plastic imitation.

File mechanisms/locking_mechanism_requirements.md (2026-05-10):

# Locking Mechanism Requirements

This document specifies four candidate hinge/locking mechanisms for the split keyboard. All mechanisms shall satisfy the parent requirements in `final_requirements.md` (REQ-F01 through REQ-F09). The mechanisms differ in how they lock the two rotation axes (fold and butterfly).

Cross-references: REQ-F01 (center mount, metal, ≤50 g), REQ-F01a (fold 0–90°, butterfly ±45°), REQ-F01c (fold-to-close / disconnect), REQ-F01d (lap rigidity), REQ-F05–F09 (cables, clevis, turnbuckles).

---

## Shared Requirements (all mechanisms)

**REQ-M01** — The mechanism shall mount at the center edge of the keyboard (between the R and T key positions), consistent with REQ-F01.

**REQ-M02** — The mechanism shall be made entirely of metal (steel, brass, or aluminium) and shall weigh at most 50 g total, consistent with REQ-F01.

**REQ-M03** — The mechanism shall provide two independent rotation axes per REQ-F01a:
  (a) Fold axis: belly-to-screen direction, 0–90°.
  (b) Butterfly axis: perpendicular to fold axis, ±45° from centerline.

**REQ-M04** — The mechanism shall allow fold-to-close for transport per REQ-F01c. If the mechanism cannot continuously rotate to 180°, the two connecting poles shall be disconnectable (magnetic breakaway or quick-release) so the halves can be folded flat against each other.

**REQ-M05** — Two hooked cable rods with turnbuckles (per REQ-F05, REQ-F09) shall connect the two halves at the top row and bottom row. These cables are the primary structure that sets the tenting angle and prevents collapse. The cable system is independent of the locking mechanism and shall be present in all mechanism options.

**REQ-M06** — The mechanism shall be operable by hand without tools. Adjusting both axes from a seated position (desk or lap) shall not require more than 10 seconds.

**REQ-M07** — On a lap (no flat surface, no cable tension line), the mechanism shall hold both axes rigid enough to resist at least 5 N of downward key-press force without angle drift.

---

## Mechanism A — Turnbuckle + Hirth Coupling (Recommended)

### Description

Each keyboard half has an angled hinge rod extending from its center edge toward a shared center eye. The rods are angled (~15° upward from the keyboard plane) so that when folded closed, the inner edges clear each other before the outer edges meet. A hinge pin through the center eye provides the fold rotation axis (belly-to-screen). A turnbuckle adjustment rod connects the two hinge rods below the keyboard plane and sets the fold angle by its effective length. On the back (bottom face) of each keyboard half, a Hirth half-moon disc lies flat. When the butterfly angle is set, the two discs mesh and a butterfly nut (or cam lever) clamps them together. A quick-release magnet at the center eye allows disconnection for fold-to-close.

### Requirements

**REQ-MA01** — Each half shall have one angled hinge rod (metal, ~25 mm length) extending from the center edge toward the shared center eye. The rod shall be angled approximately 15° above the keyboard plane to provide fold-to-close clearance.

**REQ-MA02** — A center hinge eye (metal ring/bushing) shall join the two angled rods at the fold axis. A hinge pin through the eye, oriented along the belly-to-screen axis (Z), shall provide 360° rotation for the fold degree of freedom.

**REQ-MA03** — A turnbuckle adjustment rod (metal) shall connect the two hinge rods approximately 6–10 mm below the hinge center. The turnbuckle shall set the fold angle by adjusting its effective length. Shorter length = more tented; longer length = flatter.

**REQ-MA04** — The turnbuckle attachment points to the hinge rods shall be ball-joint or clevis connections, allowing the angular offset that occurs when the fold angle changes.

**REQ-MA05** — A quick-release magnet (neodymium, ≥2 N pull force) at the center eye shall allow the two halves to disconnect for fold-to-close per REQ-M04. When disconnected, each half retains its hinge rod stub and turnbuckle arm as a captive assembly (no loose parts).

**REQ-MA06** — Each keyboard half shall have one Hirth half-moon disc mounted flat on the back (bottom face) of the keyboard, near the center edge. The disc shall lie in the XZ plane (parallel to the keyboard surface) with its toothed face oriented toward the opposing half's disc.

**REQ-MA07** — The Hirth discs shall have a diameter of 60–80 mm. Tooth count options:
  (a) 72 teeth (5° resolution): 9 selectable positions in a 45° butterfly range. Tooth width at 60 mm ≈ 2.6 mm (robust, near-standard).
  (b) 120 teeth (3° resolution): 15 selectable positions in a 45° butterfly range. Tooth width at 80 mm ≈ 2.1 mm (good precision/robustness balance).
  The selected tooth count shall be documented in the BOM.

**REQ-MA08** — A butterfly nut or cam lever shall clamp the two Hirth discs together, preventing butterfly rotation. The clamping force shall be sufficient to resist key-press force without tooth disengagement. The clamp shall be operable with one hand.

**REQ-MA09** — When the Hirth discs are unclamped (butterfly nut loosened), the user shall be able to rotate the butterfly angle freely to the next tooth position. The teeth shall self-align when clamped.

### Strengths

- Positive locking on both axes (turnbuckle geometry + Hirth teeth). No friction reliance.
- Repeatable butterfly positions (same tooth = same angle).
- Fold angle set by turnbuckle length — no separate lock operation needed for fold axis.
- Decoupled axes: changing fold does not affect butterfly, and vice versa.
- Low part count: 2 rods, 1 eye, 1 pin, 1 turnbuckle, 2 half-moon discs, 1 nut.

### Weaknesses

- Butterfly angle is discrete (5° or 3° steps), not continuous.
- Hirth discs add diameter to the underside of the keyboard (~60–80 mm).
- Custom Hirth discs may need to be ordered from a specialist manufacturer.

### Suppliers

- [TEDISA](https://www.tedisa-hirth.com/) — standard Hirth couplings from 50 mm diameter, custom tooth counts available.
- [TAC Rockford](https://tacrockford.com/product/machine-components/milling-machine/hirth-couplings-face-gears/) — custom Hirth couplings per drawing.

---

## Mechanism B — Oarlock + Bolt-draw

### Description

A central fold hinge rod provides the fold axis. Each keyboard half has an oarlock eye (metal loop) at its center edge; the hinge rod passes through both eyes. Two additional rods pass through the eyes perpendicular to the fold rod. A draw bolt runs front-to-back (Z axis) through each keyboard half — on the left half from Z-to-W, on the right half from M-to-O. The bolt has a knurled grip cylinder at the user-facing end. Rotating the grip draws the rod's end-nut inward, pulling the half into butterfly rotation. This provides continuous butterfly adjustment.

### Requirements

**REQ-MB01** — A central fold hinge rod (metal, ~20 mm length) shall pass through both oarlock eyes, oriented along the belly-to-screen axis (Z). The rod shall provide 360° fold rotation.

**REQ-MB02** — Each keyboard half shall have an oarlock eye (metal loop, ~8 mm outer diameter torus) at its center edge, rigidly attached to the keyboard body. The fold hinge rod shall pass through both eyes.

**REQ-MB03** — Two oarlock rods shall pass through the eyes perpendicular to the fold rod (left-to-right direction), one near the top row and one near the bottom row. Each rod shall have a stopper nut at each end to prevent the rod from sliding out.

**REQ-MB04** — Each keyboard half shall have one draw bolt running front-to-back (along the Z axis) through the keyboard body. The bolt shall be threaded and freely rotatable. The bolt head shall be a knurled grip cylinder (≥8 mm diameter) accessible at the user-facing edge of the keyboard.

**REQ-MB05** — Rotating the draw bolt clockwise (as viewed from the user side) shall draw the corresponding oarlock rod's end-nut inward, pulling the keyboard half into butterfly rotation. The thread pitch shall provide at least 1° of butterfly angle change per full bolt turn.

**REQ-MB06** — The draw bolt and grip cylinder shall be recessed into the keyboard frame so they do not protrude above the keycap surface or below the bottom plate by more than 2 mm.

**REQ-MB07** — Fold-to-close shall be achieved by disconnecting the oarlock rods from the eyes (magnetic or pull-apart), per REQ-M04.

### Strengths

- Continuous butterfly adjustment (no discrete steps).
- No custom precision parts needed — standard threaded rod and nuts.
- Draw bolt is protected inside the keyboard body.

### Weaknesses

- Threaded draw bolt is slow to adjust (many turns for meaningful angle change).
- Rod-through-eye has inherent clearance/play — may rattle.
- Relies on thread friction to hold butterfly angle — may drift under sustained typing force on a lap.
- Two independent draw bolts (one per half) must be adjusted symmetrically by the user — no mechanical guarantee of symmetry.
- More complex assembly: 2 eyes, 2 rods, 2 draw bolts, 4 stopper nuts.

---

## Mechanism C — Gimbal

### Description

A gimbal ring system provides two perpendicular rotation axes at the center junction. The outer ring handles the fold axis (belly-to-screen); the inner ring handles the butterfly axis. Each axis has its own thumb screw for independent locking. The keyboard halves attach to the inner ring via bracket arms.

### Requirements

**REQ-MC01** — An outer gimbal ring (metal, ~28 mm outer diameter) shall provide the fold rotation axis. The ring shall be oriented so its axis of rotation is along the belly-to-screen direction (Z).

**REQ-MC02** — An inner gimbal ring (metal, ~20 mm outer diameter) shall be mounted inside the outer ring, providing the butterfly rotation axis. The inner ring's axis shall be perpendicular to the outer ring's axis.

**REQ-MC03** — Each ring shall have a thumb screw (knurled metal, ≥8 mm head diameter) that locks rotation on that axis by friction clamping against the ring's bearing surface.

**REQ-MC04** — The outer ring shall be connected to the keyboard frame via pins or brackets along the Z axis. The inner ring shall connect to the two keyboard halves via bracket arms along the X axis.

**REQ-MC05** — Fold-to-close shall be achieved by disconnecting the bracket arms from the keyboard halves (magnetic breakaway) per REQ-M04, or by loosening the fold thumb screw and rotating through 180°.

### Strengths

- Continuous adjustment on both axes.
- Standard machining — no custom teeth or couplings.
- Compact: entire mechanism fits in a ~30 mm diameter envelope.

### Weaknesses

- Two separate lock/unlock operations required to adjust both angles.
- Friction-based locking on both axes — may drift under typing force on a lap (fails REQ-M07 without very high clamping force).
- No repeatable positions — angle must be eyeballed each time.
- Thumb screws protrude and may snag during transport.

---

## Mechanism D — Ball Joint + Cam Lever

### Description

A ball-and-socket joint at the center junction provides both rotation axes simultaneously. A cam lever (bicycle quick-release style) provides fast lock/unlock: flip the lever open, position both angles, flip closed. The ball is clamped between two socket halves, one attached to each keyboard half.

### Requirements

**REQ-MD01** — A metal ball (≥20 mm diameter) shall be mounted at the center junction, captured between two socket halves. The ball shall allow rotation around both the fold and butterfly axes simultaneously.

**REQ-MD02** — Each socket half shall be attached to one keyboard half via a bracket arm. The socket shall be lined with a high-friction material (e.g., nylon, PTFE, or rubber O-ring) to prevent angle drift when clamped.

**REQ-MD03** — A cam lever shall clamp the two socket halves together. The lever shall be operable with one hand: flip open to unlock both axes, reposition, flip closed to lock.

**REQ-MD04** — The cam lever shall generate sufficient clamping force (≥20 N axial) to prevent angle drift under key-press force per REQ-M07.

**REQ-MD05** — A clamp bolt shall pass through the ball center (along the Z axis), with the cam lever at one end and an adjusting nut at the other. The adjusting nut sets the baseline clamp tension.

**REQ-MD06** — Fold-to-close shall be achieved by loosening the cam lever and rotating through 180° (if the socket allows full rotation), or by magnetic breakaway disconnect per REQ-M04.

### Strengths

- Fastest adjustment: one lever, both axes at once.
- No discrete steps — infinite resolution on both axes.
- Simplest mechanism: ball, 2 socket halves, 1 bolt, 1 cam lever.
- Standard parts (ball bearings, cam levers are commodity items).

### Weaknesses

- Friction-only locking — the weakest hold of all four mechanisms. May drift on a lap under sustained typing.
- No repeatable positions — must re-find the angle each time.
- Ball surface wears over time, reducing friction — locking degrades with use.
- Adjusting one axis may inadvertently shift the other (axes are coupled through the ball).

---

## Comparison Matrix

| Criterion | A: Hirth | B: Oarlock | C: Gimbal | D: Ball+Cam |
|---|---|---|---|---|
| Fold lock method | Turnbuckle length | Cable tension | Thumb screw friction | Cam clamp friction |
| Butterfly lock method | Hirth teeth (positive) | Thread friction | Thumb screw friction | Cam clamp friction |
| Lap rigidity (REQ-M07) | Strong | Weak | Weak | Weak |
| Adjustment speed | Medium (1 nut) | Slow (many turns) | Slow (2 screws) | Fast (1 lever) |
| Repeatability | Exact (tooth positions) | None | None | None |
| Axes decoupled | Yes | Yes | Yes | No |
| Custom parts needed | Hirth discs | None | None | None |
| Fold-to-close | Magnetic disconnect | Rod disconnect | Disconnect or rotate | Rotate or disconnect |
| Estimated weight | 30–45 g | 35–50 g | 25–35 g | 20–30 g |

---

## Recommendation

**Mechanism A (Turnbuckle + Hirth)** is recommended. It is the only mechanism that provides positive (non-friction) locking on both axes, which is critical for lap use. The discrete butterfly steps (5° or 3°) are sufficient — most users settle on 1–2 preferred angles. The Hirth discs are the only custom part, available from TEDISA (from 50 mm) or TAC Rockford.

Recommended Hirth specification: **72 teeth (5° resolution) at 60 mm diameter**, or **120 teeth (3° resolution) at 80 mm diameter**. Both are within standard manufacturing range, with tooth widths of 2.1–2.6 mm (robust for daily use).

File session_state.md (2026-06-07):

# Session State — Handover Document

> **Read this file first in every new chat.** Update it at the end of every session.

## Current Phase

Phase 1 — Foundation (software pipeline): **COMPLETE** (all 14 requirements SELF_PASS)
Phase 2 — UI/UX Verification: **COMPLETE** (all 11 requirements SELF_PASS)
Phase 3 — 3D Render Verification: **COMPLETE** (R01-R37 all SELF_PASS except R35 NOT_STARTED)
Phase 4 — Hardware / BOM / Assembly: **COMPLETE** (all SELF_PASS — R03, R10, S10, E04, H02 fixed via R22-R25→R30-R36)
Phase 5 — Hinge & Mechanism A: **COMPLETE** (all 19 requirements SELF_PASS)
Phase 6 — Design Guidelines: **COMPLETE** (all 9 guidelines SELF_PASS)

**128+ total requirements (REQ-KM01–KM10 added). 6 USER_FAIL (S07, S07.1-S07.5 — screw placement, user told AI to stop fixing), 1 NOT_STARTED (R35), 4 SUPERSEDED (R22-R25). 32+ total user corrections.**

## Session History

| Session | Date | Requirements Attempted | Outcome |
|---|---|---|---|
| 0 | 2026-05-08 | Planning only | Created verification plan, scorecard, handover mechanism |
| 1 | 2026-05-08 | L01, L02, L03a, L03b, L04, L04a, L05, L09, L10, V01a, V01b, V02, V03, SF01 | **14/14 SELF_PASS** |
| 2 | 2026-05-08 | L06, L07, L07a, L07b, L08, L11, V04, V05, V06, SF02, SF03 | **11/11 SELF_PASS** |
| 3 | 2026-05-08 | R01–R16 | **16/16 SELF_PASS** |
| 4 | 2026-05-08 | H01–H03, S01–S12, E01–E05, B01–B03, A01–A03 | **28/28 SELF_PASS** |
| 5 | 2026-05-08 | F01–F01d, F05–F09, MA01–MA09, DG-01–DG-09 | **28/28 SELF_PASS** (19 Phase 5 + 9 Phase 6) |
| 6 | 2026-05-08 | User bug reports + runtime verification | **12 USER_FAIL detected, TDZ bug fixed, 12/12 runtime re-verified PASS** |
| 7 | 2026-05-08 | User screenshot review + root cause analysis | **6 new USER_FAIL: R03, R11, R14, SF01, S03, DG-01. Root cause: render3d.js uses wrong coordinate system** |
| 8 | 2026-05-08 | Fix 6 USER_FAIL + R17-R20 + thumb fix | **6/6 fixed, R17 fixed, R18-R20 implemented, thumb positions corrected. 101/101 SELF_PASS, 19 user corrections** |
| 9 | 2026-05-09 | Fix R19 + R20 USER_FAIL | **R19: 180° Z rotation via boardRoot group. R20: fold remapped (180°=flat, 0°=closed, 270°=tented). 21 user corrections** |
| 10 | 2026-05-09 | Fix labels/angle/hinge + R21 butterfly | **Labels counter-rotated for boardRoot, angle annotation reversed, hinge pivot at top surface, R21 butterfly fold 0-45° with butterflyRoot group. 102 requirements, 23 user corrections** |
| 11 | 2026-05-10 | Fix R18 annotation + R21 butterfly axis + MCU/battery violations | **R18: origin moved to thumb col, inner axis flipped. R21: butterfly changed from X-axis tilt to per-half Z-axis Hirth rotation, fixed compounding bug. MCU/battery/USB-C misplacement identified → 5 USER_FAIL (R03, R10, S10, E04, H02), 4 new requirements added (R22-R25). 28 user corrections** |
| 12 | 2026-05-10 | Fix MCU/battery/USB-C placement (R22-R25 + 5 USER_FAIL) | **9/9 fixed. MCU at half center on PCB, battery between bottom plate/PCB with recess, USB-C at outer edge oriented outward. All positions from bbox. 106/106 SELF_PASS, 28 user corrections** |
| 13 | 2026-05-10 | Per-layer visibility toggles (R26-R29) | **4/4 implemented. 6 layer groups with userData.layerId, setLayerVisible API, 6 checkboxes in toolbar, label sprites tagged for R28. 110/110 SELF_PASS** |
| 14 | 2026-05-10 | R30-R34, R36 implemented + R37 axes fixed | **6/7 R30-R36 implemented (R35 remains NOT_STARTED). R37 axes fixed (3rd attempt — moved to scene, world-space coords). 113/118 SELF_PASS, 30 user corrections** |
| 15-16 | 2026-05-14 | S07.1-S07.5 screw placement + T03 counter columns | **S07.1-S07.5 screw placement attempted 5-8× each, FAIL after multiple user corrections. User told AI to stop. T03 counter columns implemented in req-tracker.html. Counter data stored in per-commit status files.** |
| 17-18 | 2026-06-07 | REQ-KM01–KM10 Key Mapping feature + 3D label fixes | **Key Mapping page implemented (page 1b, now step 2). Layout presets (QWERTY/Dvorak/Colemak/Colemak-DH), key picker, save/load/export/import. 3D preview labels: 3 bugs found and fixed (meta.mirrored unreliable, left/right swap from boardRoot 180° Z rotation, thumb label rotation using raw ergogen instead of stage 1 overrides). 2 user corrections (right-half labels swapped, thumb label angle).** |

## Last Session Summary

**Sessions 17-18 — Key Mapping Feature (REQ-KM01–KM10) + 3D Label Bug Fixes**

### What was done:

#### Key Mapping Page (REQ-KM01–KM10) — IMPLEMENTED
1. **REQ-KM01**: New wizard page "Key Mapping" inserted as step 2 (between Finger Positions and 3D Preview). Wizard renumbered to 5 steps.
2. **REQ-KM02**: Switch position naming scheme `{half}{column}{row}` using lowercase alpha only `[a-z]+` (e.g., `lmt` = left-middle-top, `rit` = right-index-top).
3. **REQ-KM03**: Layout presets — QWERTY, Dvorak, Colemak, Colemak-DH (36-key, 3 layers each).
4. **REQ-KM04**: Key picker with ZMK keycode groups (Alpha, Numbers, Symbols, Modifiers, Nav, Editing, Function, Special).
5. **REQ-KM05**: Save/load keymap as standalone JSON files.
6. **REQ-KM06**: Custom mapping names validated as lowercase alpha only `[a-z]+`.
7. **REQ-KM07**: Dedicated save/load separate from project export/import.
8. **REQ-KM08**: 3D preview uses `window.configuredKeymap` (render3d.js reads it via `getActiveKeymaps()`). Firmware generation and test suite also use configured keymap.
9. **REQ-KM09**: Global `configuredKeymap` state object with `name`, `preset`, `customOverrides`, `layer0`–`layer2`.
10. **REQ-KM10**: Export/import includes keymap in project JSON.

#### 3D Preview Label Bugs — 3 BUGS FIXED (2 user corrections)

**Bug 1 — Right half showed "yuiop" layout (pre-existing)**:
- Root cause: `getKeymapLabel()` didn't reverse `colIdx` for right-half keys. Ergogen's `colIdx 0` = pinky (outer) but `layer0` stores right keys inner→outer.
- Fix: `col = isRight ? (nColsHalf - 1 - key.colIdx) : key.colIdx` in both render3d.js and wizard.html.

**Bug 2 — Right half showed left-half labels (QAZ, QWERT) — USER CORRECTION #1**:
- Root cause: `buildKeyPositionMap()` used `!!pt.meta?.mirrored` which was unreliable (could be undefined for mirror keys). The scene-building code already used the robust check `pt.meta?.mirrored === true || name.startsWith('mirror_')`.
- Fix: Updated `buildKeyPositionMap()` in render3d.js, wizard.html, and test-headless.js to use the same robust `mirror_` name prefix fallback.
- **Additional root cause**: Even with correct left/right detection, labels were visually swapped because `boardRoot.rotation.z = Math.PI` flips left↔right. Left-half geometry ends up on visual right and vice versa.
- Fix: In render3d.js `getKeymapLabel()`, split into `physRight` (which half the key belongs to, for key list lookups) and `mapRight = !physRight` (which side of the keymap array to read). This maps left geometry to right-hand labels and vice versa, so after 180° rotation the labels match the visual sides.

**Bug 3 — Thumb label angle mismatched keycaps — USER CORRECTION #2**:
- Root cause: Labels used raw ergogen point positions/rotations (`pts[k.name]`), but thumb keycap geometry uses stage 1 override positions (`leftKeys` array with overridden x/y/r from `config._stage1Keys`). Stage 1 overrides change thumb rotation significantly.
- Fix: Created `scenePositions` Map from the scene-building `leftKeys`/`rightKeys` arrays (which have stage 1 overrides applied). Label placement now uses `scenePositions.get(k.name)` instead of `pts[k.name]`.

### Changes made:
- `wip/wizard.html`: New page 1b (Key Mapping) with toolbar/grid/tabs, 5-step navigation, layout presets, key picker, save/load, export/import integration, firmware/test keymap wiring. Fixed `buildKeyPositionMap()` mirrored detection. Fixed left/right point filtering for PCB texture and instanced meshes.
- `wip/render3d.js`: Dynamic keymap via `getActiveKeymaps()`/`getZmkToLabel()`, fixed `buildKeyPositionMap()` mirrored detection, fixed `getKeymapLabel()` with `physRight`/`mapRight` split for boardRoot 180° rotation, added `scenePositions` Map for stage 1 thumb override positions, label placement uses scene positions.
- `wip/test-headless.js`: Fixed mirrored detection to use `mirror_` name prefix fallback.

## What To Do Next

**Priority 1: Verify 3D label fix — user should confirm thumb labels now align with keycaps after hard refresh**

The thumb label angle fix (using `scenePositions` instead of raw ergogen pts) was applied but not yet visually confirmed by the user. The left/right swap fix was confirmed working by user screenshot.

**Priority 2: S07.2, S07.4, S07.5 — Screw placement fixes (USER_FAIL, deferred)**

These were attempted 5-8 times each and failed. User said "Do not try to fix it." The core challenge is the boardRoot 180° Z rotation causing persistent confusion about which model half maps to which screen side. Key insight: screws are computed on left model half and cloned to right. The user sees the RIGHT model half on the LEFT side of screen (where Y, H, N keys appear). To fix S07.2 (N key), the screw needs to be placed at `matrix_inner_bottom` on the RIGHT model half, or the cloning logic needs rethinking.

**Priority 3: R35 — Post-processing script for B.Cu footprint flip**

R35 is the only NOT_STARTED requirement. It requires a post-processing step in `generate.sh` to flip the nice!nano footprint from F.Cu to B.Cu in the generated `.kicad_pcb` file.

**Priority 4: T03 verification**

T03 counter columns implemented and showing data. User confirmed layout but should verify hover notes and toggle functionality work correctly.

Other:
- Visual verification of R30-R37 (user screenshot review pending)
- The ROTATED thumb mode algorithm is still a placeholder (defaults to STRAIGHT behavior)
- Old `build3DScene()` dead code still in wizard.html (~1000 lines, no longer called)
- `convert.py` and JS `ergopadToErgogen()` should be kept in sync

## Known Issues / Blockers

- **Resolved**: R03, R10, S10, E04, H02 — MCU/battery/USB-C repositioned within board halves (session 12)
- **Resolved**: R22-R25 — Component placement from bbox, superseded by R30-R36 (session 14)
- **Resolved**: R30-R34, R36 — Backside MCU at pinky column, USB-C in frame slot, shared pocket (session 14)
- **Resolved**: R37 — Axes indicator in world space, added to scene directly (session 14, 3rd attempt)
- **Resolved**: R21 butterfly — per-half Z-axis rotation with combined fold+butterfly quaternion
- **Resolved**: R18 angle annotation — origin at thumb col, correct arc direction
- **Resolved**: R19 board orientation — boardRoot with 180° Z rotation
- **Resolved**: R20 fold semantics — 180°=flat, 0°=closed, 270°=tented
- **Resolved**: Labels counter-rotated for boardRoot
- **Resolved**: Hinge pivot at Z_SWITCH_PLATE_TOP for clean fold
- **Resolved**: T03 — Counter columns in req-tracker (session 15-16). Counter data in per-commit status files.
- **Resolved**: 3D label left/right swap — `buildKeyPositionMap()` now uses `mirror_` name prefix fallback; `getKeymapLabel()` uses `physRight`/`mapRight` split to account for boardRoot 180° Z rotation (session 17-18)
- **Resolved**: Thumb label angle mismatch — labels now use `scenePositions` Map (stage 1 overrides) instead of raw ergogen pts (session 17-18)
- **Resolved**: REQ-KM01–KM10 Key Mapping feature — wizard page 1b, presets, picker, save/load, export/import, firmware/test wiring (session 17-18)
- **OPEN / USER_FAIL**: S07.2 — Screw at N key. Model-half/screen-side confusion. Left model half = screen right. Screws computed on left model half clone to right. User deferred fix.
- **OPEN / USER_FAIL**: S07.4, S07.5 — Screws at thumb key. Repeatedly swapped between two thumb keys. User deferred fix.
- **OPEN**: Purple outlines fix — `setOutlinesVisible` now traverses `rightContent` for cloned outlineGroup (fixed in session 15-16)
- **OPEN**: Thumb label angle fix applied but not yet visually confirmed by user (session 17-18)
- The ROTATED thumb mode algorithm is a placeholder that defaults to STRAIGHT behavior
- Old `build3DScene()` dead code still in wizard.html (~1000 lines, no longer called)
- `convert.py` and JS `ergopadToErgogen()` should be kept in sync

## Key Files

| File | Purpose |
|---|---|
| `wip/final_requirements.md` | All 118+ requirements (R22-R25 superseded, R30-R37 added, S07.1-S07.5 added, T03 added) |
| `wip/compliance_scorecard.md` | Pass/fail tracking per requirement (legacy — see also req-status/*.json) |
| `wip/session_state.md` | This file — handover between sessions |
| `wip/render3d.js` | Points-based 3D keyboard renderer (Three.js). Screw placement at ~line 1160-1330. |
| `wip/wizard.html` | Main wizard UI |
| `wip/fitting.js` | Standalone fitting algorithm module |
| `wip/req-tracker.html` | Requirements tracker UI with T03 counter columns (self-attempts, self-fails, user-corrections) |
| `wip/req-tracker.js` | Requirements tracker Node.js server (port 8099). `ensureStatus()` inherits status + counters. |
| `wip/req-status/*.json` | Per-commit requirement status files (keyed by short commit hash). Contains status, comment, selfAttempts, selfFails, userCorrections. |
| `wip/build-tracker-data.js` | Builds req-tracker-data.json for static/GitHub Pages mode |
| `wip/verify-runtime.js` | Runtime verification (Playwright, 12 checks) |
| `wip/test-screws.js` | Playwright headless test for screw position verification |
| `wip/mechanisms/demo/index.html` | Interactive hinge mechanism visualization |
| `wip/geometry.md` | Coordinate system & named anchors reference |
| `claude.md` | Project directives |
| `SKILL.md` | Persona/mode |

## Critical Technical Details for Future Sessions

### boardRoot 180° Z Rotation
- `boardRoot.rotation.z = Math.PI` — flips both X and Y axes
- Visual coordinates: `visual = (-model_x, -model_y, model_z)`
- Left model half (Q,W,E,R,T / A,S,D,F,G / Z,X,C,V,B) appears on **RIGHT** side of screen
- Right model half (Y,U,I,O,P / H,J,K,L,; / N,M,,,.,/) appears on **LEFT** side of screen
- Screws are computed on left model half, then cloned to right via `boardGroup.clone(true)`

### Switch Diagonal Corner Offsets (accounting for 180° Z flip)
- User top-left = model `(+SW, -SH)` where SW=7.1mm, SH=6.4mm
- User top-right = model `(-SW, -SH)`
- User bot-left = model `(+SW, +SH)`
- User bot-right = model `(-SW, +SH)`
- `placeScrewOnDiag()` rotates these by `key.r` splay angle before computing diagonal

### Thumb Key Identifiers
- `thumb_t_inner_cluster` (model pos ~242, 221) = highest model X = leftmost/outermost in user view
- `thumb_t_outer_cluster` (model pos ~202, 193) = lowest model X = hinge-side in user view

### 3D Label Placement (render3d.js)
- **Mirrored detection**: Both `buildKeyPositionMap()` and `buildNewScene()` must use `pt.meta?.mirrored === true || name.startsWith('mirror_')`. The `meta.mirrored` property is unreliable — some ergogen points only have the `mirror_` name prefix.
- **Left/right keymap inversion**: Because `boardRoot.rotation.z = Math.PI`, left-half geometry appears on the visual right (right hand) and vice versa. `getKeymapLabel()` uses `physRight` (actual half) for key list lookups and `mapRight = !physRight` for keymap array indexing.
- **Thumb positions**: Labels must use `scenePositions` Map (populated from scene-building `leftKeys`/`rightKeys` which have stage 1 thumb overrides), NOT raw ergogen `pts`. The stage 1 override changes thumb rotation significantly.
- **Label rotation formula**: `sp.r * Math.PI / 180 + Math.PI` where `sp.r` is scene degrees (already negated). The `+ Math.PI` counters `boardRoot`'s 180° Z rotation.
- **Right-half label position**: `x = 2 * hingeX - leftSx` (mirror left match position around hingeX). Rotation: `-leftSr` (mirror + boardRoot counter).

### Key Mapping Feature (REQ-KM01–KM10)
- wizard.html page 1b (step 2 of 5), between Finger Positions and 3D Preview
- `configuredKeymap` global: `{ name, preset, customOverrides, layer0, layer1, layer2 }`
- `window.configuredKeymap` read by render3d.js (`getActiveKeymaps()`) and firmware/test generators
- Custom mapping names: lowercase alpha only `[a-z]+` (for hardware requirement references)
- Layout presets: QWERTY, Dvorak, Colemak, Colemak-DH (36-key, 3 layers)
- Layer0 array format: rows interleaved `[L_pinky..L_inner, R_inner..R_pinky, ...]` (5 left + 5 right per row), then 3+3 thumb keys

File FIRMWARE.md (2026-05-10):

# Firmware

## ZMK (recommended for wireless)

ZMK is the firmware for the nice!nano controller. No build tools needed — use GitHub Actions.

### Setup

1. Fork https://github.com/zmkfirmware/unified-zmk-config-template
2. Edit `config/boards/shields/keyboard/keyboard.keymap` with your keymap
3. Push to GitHub — Actions will build the firmware .uf2 files
4. Download the .uf2 artifacts

### Flashing

1. Double-tap reset on the nice!nano (enters bootloader)
2. It appears as a USB drive
3. Drag the .uf2 file onto the drive
4. Done — keyboard is running

### Features

- Bluetooth 5.0 (connect to 5 devices)
- USB-C wired mode
- Split keyboard support (wireless between halves)
- Battery management built-in
- Deep sleep for battery life

## QMK (alternative, wired only)

If using a Pro Micro compatible wired controller instead of nice!nano:

1. Clone https://github.com/qmk/qmk_firmware
2. Create keyboard definition under `keyboards/`
3. `qmk compile -kb keyboard -km default`
4. Flash with `qmk flash`

## Keymap

The default keymap uses 36 keys (3x5 + 3 thumb per half). Customize layers in the ZMK config:

- Layer 0: QWERTY (or your preferred alpha layout)
- Layer 1: Numbers + symbols (hold thumb key)
- Layer 2: Navigation + function keys (hold other thumb key)

## Testing with native_posix (hardware emulation)

The wizard (step 4) generates a complete ZMK shield definition and test suite. Tests use ZMK's `native_posix_64` framework — firmware compiles to a native Linux binary and runs simulated key events. No QEMU or physical hardware required.

### Prerequisites

- Docker (for self-contained build environment)

### Running tests

Download the ZIP from step 3 or step 4 of the wizard, then:

```bash
cd zmk
chmod +x run_tests.sh
./run_tests.sh
```

This builds the firmware inside a Docker container and runs three test suites:

1. **all-keys-register** — presses every key position sequentially, verifies each produces the correct HID keycode
2. **layer-switch** — holds a thumb key, presses an alpha key, verifies the alternate layer keycode
3. **matrix-ghosting** — presses two keys on the same row simultaneously, verifies no ghost keys

### Interpreting results

Each test compares actual HID keycode output against an expected snapshot. If a test fails, the diff shows which key position produced an unexpected keycode.

```
PASS: all-keys-register
PASS: layer-switch
PASS: matrix-ghosting
=== All tests passed ===
```

### Building firmware .uf2 files

```bash
cd zmk
docker compose run build-left
docker compose run build-right
ls output/keyboard_left.uf2 output/keyboard_right.uf2
```

### Adding custom tests

Create a new directory under `zmk/tests/` with:
- `native_posix_64.keymap` — mock events using `ZMK_MOCK_PRESS(row, col, delay_ms)`
- `events.patterns` — sed patterns to filter log output
- `keycode_events.snapshot` — expected HID output

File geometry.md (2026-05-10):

# Geometry Reference — Coordinate System & Named Anchors

This document defines the coordinate system used in `render3d.js` (the Three.js 3D renderer) and all named spatial anchors referenced by requirements.

---

## Coordinate System (Model/Local Space)

All geometry is built in **model space** (also called local space). A `boardRoot` group then rotates everything 180° around Z for display (R19), but all code references, bbox values, and requirements use model-space coordinates.

### Origin

The origin `(0, 0, 0)` is **not** at a board corner. X and Y origin come from ergogen's coordinate system (determined by the key layout input data). Z origin is at the table surface: `Z_BOTTOM = 0`.

### Axes

```
        Z+ (up, away from table)
        |
        |
        |
        +--------→ X+  (from pinky edge toward hinge)
       /
      /
    Y+  (along key columns, data-dependent direction)
```

| Axis | Direction (model space) | Range (typical, mm) |
|---|---|---|
| **X** | From outer pinky edge (`bbox.min.x`) toward the hinge center (`hingeX = bbox.max.x`). Positive X points inward toward the hinge. | ~0 to ~120 (depends on layout) |
| **Y** | Along the key columns (row direction). Sign depends on ergogen output + the `y = -pt.y` negation in entry construction. `bbox.min.y` and `bbox.max.y` span the rows. | ~-60 to ~60 (depends on layout) |
| **Z** | Perpendicular to the table surface. Z = 0 is the bottom of the bottom plate (table contact). Z increases upward through the layer stack toward the keycaps. | 0 to ~8.3 |

### Display Transform (boardRoot)

For the user-facing camera view (R19: thumbs face the user), all geometry is wrapped in:

```javascript
boardRoot.rotation.z = Math.PI;  // 180° rotation around Z
```

This means:
- **Screen X** = `-model_X` (hinge appears at screen-left, pinky at screen-right)
- **Screen Y** = `-model_Y` (thumbs appear closest to the camera/user)
- **Screen Z** = `model_Z` (unchanged — up is still up)

### Right Half Mirroring

The right half is **not** a rotation. It is a mirror of the left half around the hinge line `X = hingeX`:

```javascript
rightContent.translate(-hingeX, 0, 0);
rightContent.scale(-1, 1, 1);   // mirror X
rightContent.translate(hingeX, 0, 0);
```

Both halves share the same Y range and Z range. The right half's pinky edge is at `X = 2 * hingeX - bbox.min.x`.

---

## Z Layer Stack

All Z values are in millimeters from the table surface.

```
Z (mm)
 8.3   ┬ Z_KEYCAP ..................... top of keycap
       │
 7.3   │ Z_STEM ....................... top of switch stem
       │
 4.8   ┼ Z_SWITCH_PLATE_TOP ........... top of switch plate (= Z_SWITCH_BASE)
       │ T_SWITCH_PLATE = 1.2mm
 3.6   ┼ Z_SWITCH_PLATE ............... bottom of switch plate
       │ T_CORK_UPPER = 0.5mm
 3.1   ┼ Z_CORK_UPPER = Z_PCB_TOP ..... top of PCB / bottom of upper cork
       │ T_PCB = 1.6mm
 1.5   ┼ Z_PCB ........................ bottom of PCB / top of lower cork
       │ T_CORK_LOWER = 0.5mm
 1.0   ┼ Z_CORK_LOWER ................. bottom of lower cork / top of bottom plate
       │ T_BOTTOM_PLATE = 1.0mm
 0.0   ┴ Z_BOTTOM ..................... table surface (bottom of bottom plate)
```

Total stack height (excluding keycaps): `T_FRAME = 4.8mm`

---

## Named Anchors (Left Half)

These are the spatial reference points used throughout requirements and code. All values are in model space (mm).

### X-Axis Anchors

| Anchor | Code | Meaning |
|---|---|---|
| **Outer pinky edge** | `bbox.min.x` | Leftmost extent of the board outline (outer perimeter of the left half). Board edge fillet starts here. |
| **Half center X** | `halfCenterX = (bbox.min.x + hingeX) / 2` | X midpoint of the left half's board outline. |
| **Hinge line** | `hingeX = bbox.max.x` | Inner edge of the left half. The fold/butterfly pivot axis passes through this X value. |
| **Right half pinky edge** | `2 * hingeX - bbox.min.x` | Mirror of `bbox.min.x` on the right side. |

### Y-Axis Anchors

| Anchor | Code | Meaning |
|---|---|---|
| **Board Y min** | `bbox.min.y` | Bottom extent of board outline (Y direction). |
| **Board Y center** | `center.y = (bbox.min.y + bbox.max.y) / 2` | Y midpoint of the board. Also `halfCenterY` and `hingeCenterY`. |
| **Board Y max** | `bbox.max.y` | Top extent of board outline. |

### Z-Axis Anchors

| Anchor | Code | Value (mm) |
|---|---|---|
| **Table surface** | `Z_BOTTOM` | 0.0 |
| **Bottom plate top** | `Z_CORK_LOWER` | 1.0 |
| **PCB bottom** | `Z_PCB` | 1.5 |
| **PCB top** | `Z_PCB_TOP` | 3.1 |
| **Switch plate top** | `Z_SWITCH_PLATE_TOP` | 4.8 |
| **Keycap top** | `Z_KEYCAP` | 8.3 |

### Key Position Anchors

| Anchor | How to compute | Meaning |
|---|---|---|
| **Pinky column keys** | `leftKeys.filter(k => k.zone === 'matrix' && k.colIdx === 0)` | The 3 keys in the outermost (pinky) column |
| **Pinky inner edge X** | `Math.max(...pinkyKeys.map(k => k.x)) + keyHalfWidth` | Inside edge of pinky key footprints (toward hinge) |
| **Pinky outer edge X** | `Math.min(...pinkyKeys.map(k => k.x)) - keyHalfWidth` | Outside edge of pinky key footprints (toward board edge) |
| **Pinky Y center** | `(Math.min(...pinkyKeys.map(k => k.y)) + Math.max(...pinkyKeys.map(k => k.y))) / 2` | Y midpoint of pinky column |
| **Inner column keys** | `leftKeys.filter(k => k.zone === 'matrix' && k.colIdx === 4)` | The 3 keys in the innermost matrix column |
| **Thumb keys** | `leftKeys.filter(k => k.zone !== 'matrix')` | The 3 thumb cluster keys |

### Component Position Anchors (Current)

| Anchor | Code | Meaning |
|---|---|---|
| **MCU position** | `(nanoLeftX, nanoY)` | Currently at `halfCenterX, halfCenterY` — to be revised per R30-R36 |
| **Battery position** | `(battX, battY)` | Currently at `halfCenterX, halfCenterY - 18` |
| **USB-C position** | `(usbX, usbY)` | Currently at `bbox.min.x + 3.75, halfCenterY` |

---

## Diagram — Left Half Top View (Model Space)

```
  bbox.min.y
       │
       ▼
  ┌────────────────────────────────────────┐  ← bbox.min.x (outer pinky edge)
  │                                        │
  │   [pinky]  [ring]  [middle]  [index]  [inner]  │
  │   col 0    col 1   col 2     col 3    col 4    │
  │                                        │
  │              [thumb cluster]            │
  │              col 5 (zone=thumb)         │
  │                                        │
  └────────────────────────────────────────┘  ← hingeX (hinge/inner edge)
       ▲
       │
  bbox.max.y

  X increases →  (from bbox.min.x toward hingeX)
  Y increases ↓  (from bbox.min.y toward bbox.max.y)
```

Note: The exact Y direction sign depends on ergogen data. The diagram shows the conceptual layout; actual `bbox.min.y` may be at the top or bottom depending on input.

---

## 3D Scene Axis Indicator

The 3D render includes a visual XYZ axis indicator at the model-space origin `(0, 0, 0)` with:
- **Red line** = X axis (toward hinge)
- **Green line** = Y axis (along columns)
- **Blue line** = Z axis (up from table)
- Tick marks at 10mm and 100mm intervals
- Axis labels (X, Y, Z) at the positive ends

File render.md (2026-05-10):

# 3D Rendering & Interactive Viewer

## Browser-based 3D Preview (recommended)

The wizard includes a built-in Three.js 3D preview with no installation required.

```bash
cd /home/a/git/git/keyboard/wip
python3 -m http.server 8080
# Open http://localhost:8080/wizard.html → go to Step 2
```

**Features:**
- PBR materials with environment-based reflections (bamboo, cork, brushed steel, brass, FR-4 PCB)
- Procedural textures: wood grain, cork pores, PCB copper traces, brushed metal
- Per-key components: Cherry MX ULP switch housings, keycaps, stems, SOD-123 diodes
- Key press animation (click any key — 1.8mm travel with easeOutQuad)
- M2 countersunk screws and brass heat-set inserts
- nice!nano v2 controllers with USB-C port and gold pads
- LiPo batteries with wiring
- Ball joint hinge with rod-end bearing and thumb nut
- Turnbuckle cables with clevis pins (CatmullRomCurve3 droop)
- Fold angle slider (0–160 degrees)
- Toggle checkboxes for cables, hinge, battery visibility

**Controls:**
- **Left-drag** — orbit
- **Right-drag** — pan
- **Scroll** — zoom
- **Click a key** — press animation

**Technical details:**
- Three.js r160 with ES module import maps
- ACES filmic tone mapping, SRGB color space
- PMREMGenerator + RoomEnvironment for metallic reflections
- InstancedMesh for efficient rendering of 34+ switches, keycaps, screws
- Raycaster hit detection on keycap instances

## Desktop Tools

### Install

```bash
# OpenSCAD (interactive 3D viewer for full assembly)
sudo apt install openscad

# KiCad (PCB 3D viewer) — use pcbnew to open .kicad_pcb files
sudo apt install kicad

# FreeCAD (via snap — not in apt on some distros)
sudo snap install freecad

# STL viewers (any of these work)
sudo apt install meshlab
```

macOS:
```bash
brew install --cask openscad kicad freecad meshlab
```

### Interactive 3D assembly viewer (OpenSCAD)

Open `assembly.scad` in OpenSCAD for a fully interactive 3D view with all components:

```bash
cd /home/a/git/git/keyboard/wip
openscad builds/<name>/assembly.scad
```
(Right click to move the board/frame/fixed position).

**Controls:**
- **Left-drag** — rotate
- **Right-drag** — pan
- **Scroll** — zoom
- **View → Show Edges** — see wireframe
- **View → Show Axes** — orientation reference

**Cross-section (inspect internals):**
- **View → Thrown Together** — see through transparent surfaces
- Or add `#` before any shape in the .scad file to make it transparent

**Components visible:**
- Bamboo plywood frame (warm tan, 4.8mm total height, 4mm wall)
- Bottom plate (grey, 1.0mm)
- Cork gaskets (brown, 0.5mm each) — between bottom plate/PCB and PCB/switch plate
- PCB (green, 1.6mm) — on cork gasket
- Switch plate (grey, 1.2mm) — with cutouts for Cherry ULP switches
- nice!nano MCU (green PCB with black chip) — one per half
- USB-C connectors (grey) — on the nice!nano, inner edge of each half
- 301230 LiPo battery (blue, 30x12x3mm) — along board edge near MCU
- Ball joint hinge (center, rod-end bearing with thumb nut lock)
- Two turnbuckle cables with quick-release clevis pins (top and bottom)

**Toggle components** by editing variables at the top of assembly.scad:
```
show_cables  = true;   // turnbuckle cables with clevis pins
show_hinge   = true;   // ball joint hinge
show_battery = true;   // LiPo battery
```

**Folding simulation:**

The keyboard is two separate halves connected by a hinge. You can visualize folding by changing the `fold_angle` variable:
```
fold_angle = 0;    // flat (working position)
fold_angle = 90;   // half folded
fold_angle = 160;  // fully closed for transport (ball joint limit)
```

Or use the OpenSCAD Customizer panel (**View → Hide Customizer** to toggle) — it provides a slider for `fold_angle` from 0 to 160.

**Connection points:**

When `fold_angle = 0` (flat), red ring markers show where the two halves connect:
- 2 markers at the hinge (left and right mounting flanges)
- 4 markers at cable attachment points (top-left, top-right, bottom-left, bottom-right)

The assembly.scad regenerates automatically when you re-run `generate.sh`. Keeping OpenSCAD open and pressing F5 reloads the file.

A pre-rendered `assembly.png` is also generated if OpenSCAD is installed.

### View the PCB in 3D (KiCad)

```bash
cd /home/a/git/git/keyboard/wip
pcbnew builds/<name>/pcbs/keyboard_v7.kicad_pcb
```

Then: **View → 3D Viewer** — shows the PCB with component footprints.

Note: use `pcbnew`, not `kicad`. Use the `_v7` file for KiCad 7+.

### View cases/plates as STL

```bash
meshlab builds/<name>/cases/switch_plate.stl
meshlab builds/<name>/cases/bottom_plate.stl
meshlab builds/<name>/cases/wooden_frame.stl
```

Or drag into any online STL viewer: https://www.viewstl.com/

### View outlines (FreeCAD / browser)

```bash
# DXF outlines
freecad builds/<name>/outlines/board.dxf
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

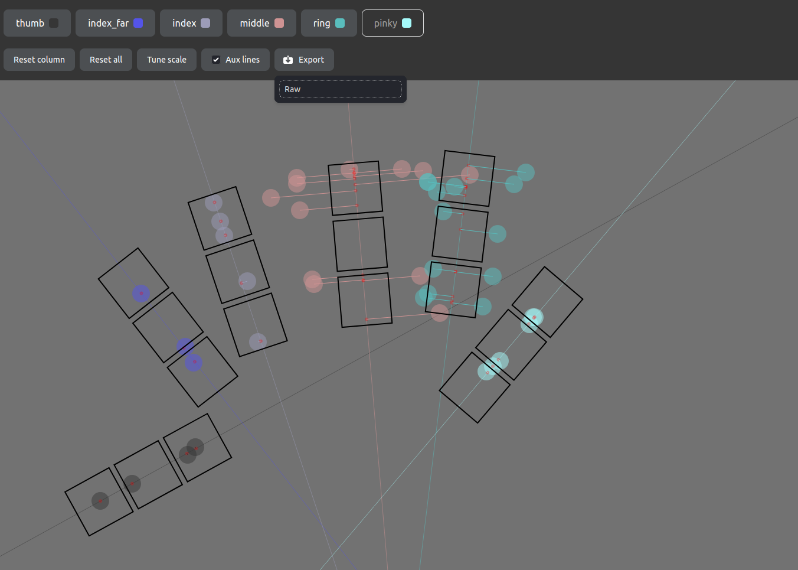
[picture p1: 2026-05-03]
ergopad_website_screenshot_example.png

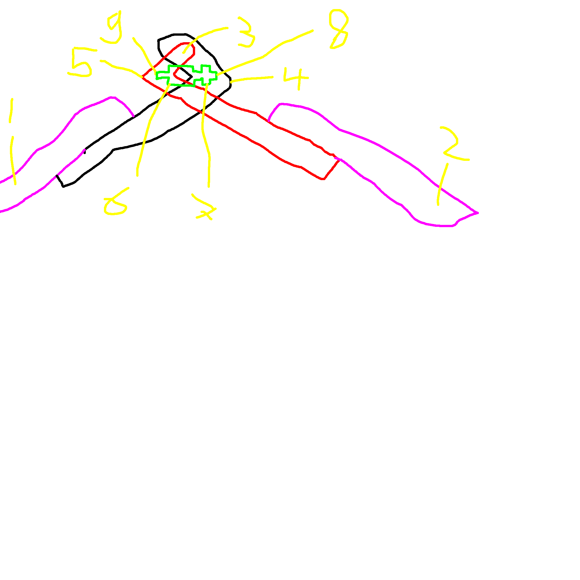
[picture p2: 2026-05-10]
mechanisms/mechanism_1.png

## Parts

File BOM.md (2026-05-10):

# Bill of Materials — Phase 0

All components are no-solder. PCB is assembled by the fab house (PCBA service).

## Electronics (per keyboard = 2 halves)

| Qty | Component | Unit Price | Total | Source |
|-----|---|---|---|---|
| 36 | Cherry MX ULP Tactile switch | €0.90 | €32.40 | [keeb.supply](https://keeb.supply/products/cherry-mx-ulp) |
| 36 | 1N4148W SOD-123 diode | €0.02 | €0.72 | [LCSC](https://www.lcsc.com/product-detail/C81598.html) |
| 36 | ULP keycap (15x15mm) | ~€1.50 | ~€54 | Harvest from [Cherry KW X ULP](https://www.amazon.com/Cherry-Wireless-Mechanical-Keyboard-Switches/dp/B0C4HRP34X) or [AliExpress Dell module](https://www.aliexpress.com/item/1005005578673316.html) |
| 2 | nice!nano v2 | €25.00 | €50.00 | [42keebs.eu](https://42keebs.eu/shop/parts/controllers/nice-nano-v2-wireless-controller/), [splitkb.com](https://splitkb.com/products/nice-nano), [nicekeyboards.com](https://nicekeyboards.com/nice-nano/) |
| 2 | Mill-Max 315 socket strip (12-pin) | €4.00 | €16.00 | [splitkb.com](https://splitkb.com/products/mill-max-low-profile-sockets), [Arrow](https://www.arrow.com/en/products/315-43-120-41-003000/mill-max) |
| 2 | 301230 LiPo battery (110mAh) | €3.00 | €6.00 | [AliExpress](https://www.aliexpress.com/w/wholesale-301230-lipo.html) |
| 2 | MSK-12C02 power switch | €0.20 | €0.40 | [LCSC](https://www.lcsc.com/product-detail/C431541.html) |
| 1 | USB-C cable | €5.00 | €5.00 | [Amazon](https://www.amazon.com/s?k=usb-c+cable+short) |
| 2 | PCB (assembled, PCBA) | ~€15.00 | ~€30.00 | [JLCPCB](https://jlcpcb.com/pcb-assembly) |

**Phase 0 electronics total: ~€195**

## Connectivity Options

The nice!nano supports all three modes out of the box:
1. **Wired**: USB-C from one half directly to laptop
2. **Split wired**: USB-C between halves, one USB-C to laptop
3. **Wireless**: Bluetooth from both halves to laptop (no cables)

## How to Order

### PCB (JLCPCB)
1. Go to [jlcpcb.com](https://jlcpcb.com/quote)
2. Upload `builds/<name>/pcbs/keyboard.kicad_pcb` (export Gerbers from KiCad first)
3. Enable "PCB Assembly" toggle
4. Upload BOM CSV + pick-and-place CPL file
5. They solder all SMD components (switches, diodes)
6. Cost: ~€8 setup + €0.0017/joint + component cost. For 36 switches + 36 diodes ≈ €15/board

### MCU (no solder)
1. Insert Mill-Max sockets into PCB holes
2. Drop nice!nano onto sockets
3. Done — removable, no soldering

### Switches (no solder)
Cherry ULP switches clip into the alignment holes on the assembled PCB. The SMD contact pads are pre-soldered by JLCPCB during assembly.

---

# Bill of Materials — Phase 1

## Bamboo Plywood Frame

| Qty | Component | Unit Price | Total | Source |
|-----|---|---|---|---|
| 2 | Bamboo plywood sheet 200×150×2mm | €6.00 | €12.00 | [Amazon](https://www.amazon.com/s?k=bamboo+plywood+2mm), [AliExpress](https://www.aliexpress.com/w/wholesale-bamboo-plywood-2mm.html) |

Two-part milled frame per half — bottom piece (backbone + edge lip) and top bezel. Cut using `frame_with_holes.dxf` — CNC router or laser cutter. Bamboo plywood is cross-laminated (MOR 40-60 MPa), viable at 2mm thickness with 4mm wall width.

## Cork Gaskets

| Qty | Component | Unit Price | Total | Source |
|-----|---|---|---|---|
| 1 | Natural cork gasket sheet 0.5mm, A4 | €5.00 | €5.00 | [Amazon](https://www.amazon.com/s?k=cork+gasket+sheet+0.5mm), [AliExpress](https://www.aliexpress.com/w/wholesale-cork-gasket-sheet-0.5mm.html) |

Cut two gaskets per half from `board.dxf` outline. Placed between layers: bottom plate → cork → PCB → cork → switch plate. Eliminates rattle, dampens acoustics, compensates tolerances.

## Ball Joint Hinge

| Qty | Component | Unit Price | Total | Source |
|-----|---|---|---|---|
| 1 | M6 rod-end bearing (ball joint) | €3.00 | €3.00 | [AliExpress](https://www.aliexpress.com/w/wholesale-m6-rod-end-bearing.html), [eBay](https://www.ebay.com/sch/i.html?_nkw=m6+rod+end+bearing) |
| 1 | M6 thumb nut (locking) | €0.50 | €0.50 | [AliExpress](https://www.aliexpress.com/w/wholesale-m6-thumb-nut.html) |
| 2 | M6 threaded rod stub 15mm | €0.30 | €0.60 | [AliExpress](https://www.aliexpress.com/w/wholesale-m6-threaded-rod-stud.html) |
| 2 | Mounting plate (flat bracket, drilled for M2) | €1.00 | €2.00 | [AliExpress](https://www.aliexpress.com/w/wholesale-flat-bracket-M2.html) or 3D-printed |

Rod-end bearing mounts at the inner edge between halves. Provides free tilt in all axes for tenting adjustment. Thumb nut locks chosen angle. Range: ~140-160° fold (not full 180° flat).

## Turnbuckle Cables with Quick-Release Clevis Pins

| Qty | Component | Unit Price | Total | Source |
|-----|---|---|---|---|
| 2 | Braided steel cable 1.5mm × 250mm | €0.50 | €1.00 | Hardware store or [Amazon](https://www.amazon.com/s?k=braided+steel+cable+1.5mm) |
| 2 | Small turnbuckle (M3, ~40mm body) | €1.50 | €3.00 | [AliExpress](https://www.aliexpress.com/w/wholesale-small-turnbuckle-m3.html), hardware store |
| 2 | Quick-release clevis pin (spring-loaded ball detent) | €2.50 | €5.00 | [AliExpress](https://www.aliexpress.com/w/wholesale-quick-release-clevis-pin.html), [McMaster](https://www.mcmaster.com) |
| 2 | Clevis bracket (recessed into frame edge) | €1.00 | €2.00 | [AliExpress](https://www.aliexpress.com/w/wholesale-clevis-bracket-small.html) or 3D-printed |
| 4 | Cable crimp eyelet | €0.20 | €0.80 | [Amazon](https://www.amazon.com/s?k=cable+crimp+eyelet+1.5mm) |

Cables serve dual purpose: structural support (prevents collapse under gravity) and tenting angle adjustment via turnbuckle length. One cable top, one bottom. Quick-release clevis pins allow one-handed press-button detach for folding.

## Mechanism A — Hirth Coupling Components

| Qty | Component | Unit Price | Total | Source |
|-----|---|---|---|---|
| 2 | Hirth half-moon coupling disc, 72-tooth 60mm | €45.00 | €90.00 | [TEDISA](https://www.tedisa-hirth.com/), [TAC Rockford](https://tacrockford.com/product/machine-components/milling-machine/hirth-couplings-face-gears/) |
| 1 | Butterfly nut M6 (wing nut, stainless steel) | €1.00 | €1.00 | [AliExpress](https://www.aliexpress.com/w/wholesale-m6-butterfly-wing-nut-stainless.html), [Amazon](https://www.amazon.com/s?k=m6+butterfly+wing+nut+stainless) |
| 2 | Neodymium disc magnet 8×3mm (≥2N pull force) | €0.50 | €1.00 | [AliExpress](https://www.aliexpress.com/w/wholesale-neodymium-disc-magnet-8x3mm.html), [Amazon](https://www.amazon.com/s?k=neodymium+disc+magnet+8x3mm) |

Hirth discs mount flat on the back (bottom face) of each keyboard half near the center edge. When the butterfly angle is set, the two discs mesh and the butterfly nut clamps them together. 72 teeth give 5° resolution (9 selectable positions in ±45° butterfly range). Neodymium magnets at the center eye allow quick-release disconnect for fold-to-close.

## Fold-to-Close Accessories

| Qty | Component | Unit Price | Total | Source |
|-----|---|---|---|---|
| 2 | Elastic band (silicone, ~150mm circumference) | €0.30 | €0.60 | [Amazon](https://www.amazon.com/s?k=silicone+elastic+band+150mm), [AliExpress](https://www.aliexpress.com/w/wholesale-silicone-elastic-band.html) |

Elastic bands secure the cables around the closed keyboard when folded, regardless of turnbuckle position. No turnbuckle length adjustment needed for folding/unfolding.

**Phase 1 total: ~€128**

---

# Bill of Materials — Phase 2

## Assembly Hardware

| Qty | Component | Unit Price | Total | Source |
|-----|---|---|---|---|
| 14 | M2×5mm countersunk flat-head screw | €0.05 | €0.70 | [AliExpress](https://www.aliexpress.com/w/wholesale-m2-5mm-countersunk-screw.html), [McMaster](https://www.mcmaster.com) |
| 14 | M2 heat-set brass threaded insert | €0.15 | €2.10 | [AliExpress](https://www.aliexpress.com/w/wholesale-m2-heat-set-insert.html), [CNCKitchen](https://cnckitchen.store) |

Heat-set inserts are pressed into the bamboo frame from below using a soldering iron (set to ~200°C). Countersunk flat-head screws sit flush from the top.

**Phase 2 total: ~€2.80**

### Assembly order (per half)
1. Press M2 heat-set inserts into bottom frame piece (7 per half)
2. Place bottom plate (1.0mm) inside frame
3. Place cork gasket (0.5mm) on bottom plate
4. Place PCB on cork gasket
5. Place cork gasket (0.5mm) on PCB
6. Place switch plate (1.2mm) on cork gasket
7. Place top bezel frame piece
8. Secure from top with M2 countersunk screws into heat-set inserts (flush)
9. Press Cherry ULP switches into plate cutouts
10. Drop nice!nano onto Mill-Max sockets

Total assembled thickness: **4.8mm** (1.0 bottom + 0.5 cork + 1.6 PCB + 0.5 cork + 1.2 switch plate)

Screw positions: 7 per half — see `outlines/mounting_holes.dxf` for exact coordinates.

### Folding & cables
1. Mount ball joint at inner edge between halves, secure with mounting plates
2. Tighten thumb nut to lock ball joint at desired tenting angle
3. Attach turnbuckle cables between clevis brackets (one top, one bottom)
4. Adjust turnbuckle length to set tenting tension
5. To fold: press clevis pin buttons to release cables, fold halves inward

---

**Grand total (all phases): ~€326**

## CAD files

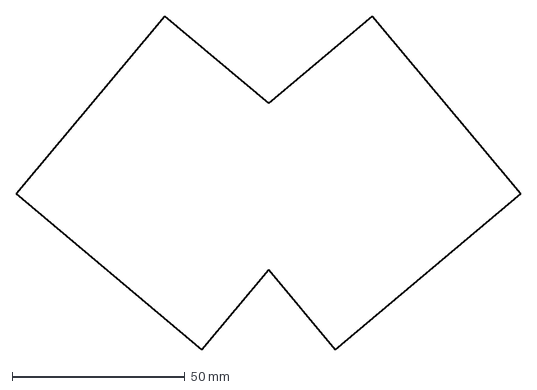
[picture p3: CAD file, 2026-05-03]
builds/ergogen_xyz/outlines/_thumb_bridge_frame.dxf
146.0 x 96.3 mm

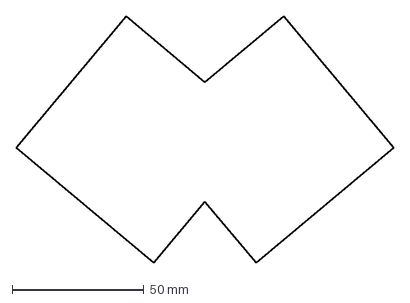
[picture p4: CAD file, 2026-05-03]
builds/ergogen_xyz/outlines/_thumb_bridge.dxf
143.2 x 93.5 mm

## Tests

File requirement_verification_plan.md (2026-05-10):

# Requirement Verification Plan

All verification shall be automated and execute without user input. I will write scripts, take my own screenshots, simulate user taps, run headless browsers, parse outputs, and programmatically assert pass/fail. No human in the loop.

**Verification categories:**
- **CODE** — Static analysis of source code, config files, or generated outputs.
- **SCRIPT** — A Node.js/Python script that runs a computation and asserts numeric/structural results.
- **E2E** — Playwright or Selenium browser automation that drives the UI, captures screenshots, and asserts visual/functional outcomes.
- **BUILD** — Run `generate.sh` or `ergogen` CLI and verify outputs exist and are structurally correct.
- **3D** — Headless Three.js render to canvas/PNG, pixel-level or geometry-level assertions.
- **DOC** — Verify a document exists, contains required sections, and passes structural checks.

**Tools available:**
- `node test-headless.js` — ergogen pipeline verification
- `node validate-stages.js` — stage 1 vs stage 2 comparison
- `python3 control.py` — Selenium browser automation with screenshot capture
- Playwright (`ergopad/e2e/`) — E2E browser tests for ergopad
- Ergogen test suite (`ergogen/test/`) — Mocha with 100% coverage
- `generate.sh` — Full build pipeline
- `convert.py` — JSON-to-YAML conversion
- Node.js with ergogen.js library — headless ergogen processing
- Python for numerical assertions, JSON parsing, geometry math

---

## 1. Layout & Input

### REQ-L01 — Passhutk ergopad captures taps → JSON
**Type:** E2E
**Plan:** Playwright test: launch ergopad app, programmatically click canvas at known (x,y) coordinates for each column (pinky, ring, middle, index, inner, thumb — at least 4 taps each). Trigger export. Parse the downloaded/clipboard JSON. Assert: (a) JSON has `positions` object with all 6 column keys, (b) each column array has length ≥ 4, (c) each entry has `x` and `y` numeric fields, (d) coordinates are within canvas bounds.

### REQ-L02 — Computed switch positions → config.yaml via converter
**Type:** SCRIPT
**Plan:** For each of the 9 example JSONs in `wip/examples/`: (a) Run `convert.py` to produce `config.yaml`. (b) Verify config.yaml is valid YAML. (c) Parse and assert it contains `zones` with columns matching input. (d) Verify the converter reads from computed switch positions (item b in JSON), not raw taps — inject a JSON where raw taps differ from computed positions; assert config.yaml matches computed positions, not taps.

### REQ-L03a — Fitting algorithm determinism
**Type:** SCRIPT
**Plan:** Write `test-determinism.js`: For each example JSON, run the fitting algorithm 100 times with identical inputs (same taps, PPM, algorithm). Capture all 100 result sets. Assert bit-identical output across all runs (use `JSON.stringify` comparison — zero tolerance). Test with all 3 thumb modes.

### REQ-L03b — Ergogen output within 0.05mm / 0.05° of computed positions
**Type:** SCRIPT
**Plan:** Extend `test-headless.js`: For each example JSON, (a) extract computed switch positions from JSON. (b) Run ergopadToErgogen → config.yaml → ergogen.process(). (c) Extract ergogen output points. (d) For every key, compute Euclidean distance between computed and ergogen positions; assert < 0.05 mm. (e) Compute rotation delta; assert < 0.05°. (f) Report per-key deltas in a table. Fail hard on any exceedance.

### REQ-L04 — Each column has exactly 3 keys, ≥3 taps
**Type:** SCRIPT + E2E
**Plan (SCRIPT):** Parse every example JSON — assert each column has ≥ 3 entries in raw taps. After fitting, assert exactly 3 computed switch positions per column.
**Plan (E2E):** Playwright: tap only 2 times in one column, then try to proceed. Assert system prevents progression or shows error. Tap 3 times — assert system accepts. Tap 20 times — assert system still produces exactly 3 switches.

### REQ-L04a — 36 keys total (6 columns × 3 keys × 2 halves)
**Type:** SCRIPT + BUILD
**Plan:** After running ergogen on any config.yaml: count total points in ergogen output (including mirror). Assert exactly 36. Also verify in BOM (when generated) that switch count = 36, keycap count = 36.

### REQ-L05 — Keys in a column are colinear and perpendicular to fitted line
**Type:** SCRIPT
**Plan:** For each matrix column in each example JSON: (a) Compute fitted line via regression. (b) For each of the 3 switch centers, compute signed distance from the fitted line; assert < 1e-6 mm (they should be on the line). (c) Compute each switch rectangle's rotation; assert all 3 are identical (within 1e-6°). (d) Assert rotation = `atan(slope) + PI/2` (perpendicular to line).

### REQ-L06 — Only thumb cluster has independent splay
**Type:** CODE
**Plan:** Parse generated config.yaml. For every non-thumb column (`pinky`, `ring`, `middle`, `index`, `inner`), assert `splay` is either absent or 0. For the thumb zone, assert splay may be nonzero (for ROTATED mode). Verify this across all 3 thumb modes.

### REQ-L07 — Three thumb modes: STRAIGHT, ROTATED, ERGOGEN
**Type:** SCRIPT
**Plan:** Write `test-thumb-modes.js`: For one example JSON with thumb taps, run the fitting algorithm in each of the 3 modes:
- **STRAIGHT:** Assert all 3 thumb keys are colinear (max deviation from regression line < 1e-6 mm). Assert all rotations identical. Assert generated config.yaml has splay=0 for thumb zone.
- **ROTATED:** Assert all 3 thumb keys lie on a circle (fit circle, assert max radial error < 1e-6 mm). Assert each key rotation = tangent to arc. Assert config.yaml has uniform nonzero splay.
- **ERGOGEN:** Provide known ergogen params, assert config.yaml passes them through verbatim (character-level match of splay/spread/origin values).

### REQ-L07a — Thumb mode + params stored in export JSON
**Type:** SCRIPT
**Plan:** Run export in each thumb mode. Parse JSON. Assert: (a) field `thumbMode` exists and equals `STRAIGHT`/`ROTATED`/`ERGOGEN`. (b) For STRAIGHT: `thumbParams.lineAngle` present. (c) For ROTATED: `thumbParams.center`, `thumbParams.radius`, `thumbParams.angularOffsets` present. (d) For ERGOGEN: `thumbParams.spread`, `thumbParams.splay`, `thumbParams.origin` arrays present.

### REQ-L07b — Switching thumb mode redraws immediately, preserves taps
**Type:** E2E
**Plan:** Playwright: (a) Tap 5 thumb positions. (b) Screenshot canvas (state A). (c) Switch to ROTATED mode. (d) Screenshot canvas (state B). (e) Assert state A ≠ state B (pixel diff > threshold — keys moved). (f) Read stored thumb taps — assert count still 5 (preserved). (g) Switch back to STRAIGHT. (h) Screenshot canvas (state C). (i) Assert state C = state A (same positions restored).

### REQ-L08 — Tune Scale calibration modal
**Type:** E2E
**Plan:** Playwright: (a) Open Tune Scale modal. (b) Assert reference line is visible. (c) Enter 100 mm. (d) Close modal. (e) Read `localStorage` for calibration value; assert it's set. (f) Reload page. (g) Read `localStorage` again; assert value persists. (h) Compute expected PPM = CSS width of reference line / 100; assert stored PPM matches.

### REQ-L09 — ergopadToErgogen converter reconstructs positions within tolerance
**Type:** SCRIPT
**Plan:** This is directly tested by REQ-L03b verification. Additionally: write a test that specifically validates the cumulative rotation stack inverse-solve by constructing a config with known splay values, running ergogen forward, then running the inverse solver backward, and asserting round-trip error < 0.05 mm.

### REQ-L10 — JSON export/import completeness
**Type:** SCRIPT
**Plan:** (a) Export JSON from a known state. Parse and assert presence of all required fields: `positions[column][].{x,y}` (raw taps), `computedSwitches[column][].{center:{x,y}, rotation, size:{w,h}}`, `fittingAlgorithm[column]`, `thumbMode`, `thumbParams`, `calibratedPPM`, `canvasWidth`, `canvasHeight`. (b) Modify `canvasWidth` in the JSON (simulate different screen). Reload. Assert raw taps are scaled correctly (proportional to canvas ratio). Assert recomputed switches match stored switches within 1e-6 mm.

### REQ-L11 — Zoom in/out with keyboard shortcuts
**Type:** E2E
**Plan:** Playwright: (a) Record initial switch visual size on canvas. (b) Press zoom-in shortcut. (c) Screenshot. Assert switches are visually larger (bounding box comparison). (d) Press zoom-out shortcut. Assert switches return to original size. (e) Verify the shortcuts don't trigger browser default actions (no page zoom, no find dialog). (f) If Tune Scale was set, assert calibration value changed proportionally.

---

## 2. Validation

### REQ-V01a — Boundary 1: taps → computed switches determinism on reload
**Type:** SCRIPT
**Plan:** For each example JSON: (a) Load JSON, extract stored computed positions. (b) Rerun fitting algorithm from stored raw taps + PPM + algorithm. (c) Compare recomputed vs stored. Assert max delta < 1e-6 mm for position, < 1e-6° for rotation. If any delta exceeds this, report the key and deltas, and fail.

### REQ-V01b — Boundary 2: computed switches → ergogen within 0.05mm/0.05°
**Type:** SCRIPT
**Plan:** Same as REQ-L03b. Run `test-headless.js` for all example JSONs. Assert per-key position error < 0.05 mm, rotation error < 0.05°. Generate a CSV report of all deltas.

### REQ-V02 — Relative key arrangement preserved
**Type:** SCRIPT
**Plan:** For each pair of adjacent keys (within column: k1→k2→k3; between columns: closest pairs): compute center-to-center distance and direction vector from computed positions. Compute same from ergogen output. Assert distance deltas < 0.1 mm and direction angle deltas < 0.1°. Detect if any key pair has swapped order (sign of direction vector flipped).

### REQ-V03 — No overlapping switches
**Type:** SCRIPT
**Plan:** For every pair of keys (all 18 per half, 153 pairs): compute center-to-center distance. Assert distance > Cherry ULP switch housing width (look up from datasheet — approximately 13.8 mm). Run this on both computed positions and ergogen output. Fail if any pair overlaps.

### REQ-V04 — Validation recomputes on every tap add/remove
**Type:** E2E
**Plan:** Playwright: (a) Add a tap. Assert validation ran (check for validation result element or console log). (b) Add more taps until 3 per column. Assert validation ran each time (count validation invocations via console.log interception). (c) Remove a tap. Assert validation ran again. Verify no "navigate to separate page" step is required.

### REQ-V05 — Validation errors displayed on canvas
**Type:** E2E
**Plan:** Playwright: (a) Deliberately create an overlapping switch layout (tap two columns at nearly the same position). (b) Screenshot canvas. (c) Assert red overlay is visible (pixel color sampling at known key positions — look for red channel > 200). (d) Assert summary message element exists below toolbar, contains error text. (e) Fix the overlap (move taps apart). (f) Assert green indicators appear, error message clears.

### REQ-V06 — Next button disabled on validation error
**Type:** E2E
**Plan:** Playwright: (a) Create an invalid layout (overlapping switches). (b) Assert Next button is disabled (`button.disabled === true` or CSS `pointer-events: none`). (c) Assert error is "displayed prominently" (element has font-size ≥ 14px, color is red-ish). (d) Fix the layout. (e) Assert Next button becomes enabled.

---

## 3. Hardware — Switches & Keys

### REQ-H01 — Cherry MX ULP switches
**Type:** CODE + BUILD
**Plan:** (a) Grep ergogen footprint files for `cherry_ulp` usage. Assert config.yaml specifies this footprint. (b) Verify the KiCad PCB output contains Cherry ULP footprints (parse .kicad_pcb, search for footprint name). (c) Verify BOM lists "Cherry MX ULP" with correct quantity (36).

### REQ-H02 — No soldering except ULP switches
**Type:** CODE + DOC
**Plan:** (a) Parse BOM. For each electrical component, check the assembly method field. Assert only "Cherry MX ULP" has "solder" method. MCU, battery connector, USB-C shall list "hot-swap", "press-fit", "pin header", or "socket". (b) Parse `grandma_builder.md` — assert no soldering steps except for ULP switch attachment.

### REQ-H03 — Keycap legends displayed
**Type:** 3D + DOC
**Plan:** (a) In render3d.js output, for each keycap mesh: assert it has a child plane mesh with a canvas texture. (b) Verify the texture contains non-empty text (render to image, assert pixel variance > threshold — not blank). (c) Verify BOM includes "keycap legend set" or "sticker overlay sheet" as a line item.

---

## 4. Hardware — Structure

### REQ-S01 — Two separate halves
**Type:** BUILD + 3D
**Plan:** (a) Run ergogen. Assert output contains a mirror operation (or two separate zone definitions) producing 2 halves. (b) In 3D render, assert there are exactly 2 top-level keyboard body meshes. (c) At fold angle 0°, butterfly 0°: assert the two body meshes do not overlap (bounding box intersection test).

### REQ-S02 — Smoothed board outline
**Type:** BUILD + CODE
**Plan:** (a) Run ergogen to generate outline SVG/DXF. (b) Parse the outline path. (c) Assert: no 90° staircase corners remain (all corner angles > 90° or filleted). (d) Measure index side straightness (fit line to index-side points, assert max deviation < 0.5 mm). (e) Measure top edge curvature (fit arc, assert it's a single continuous arc). (f) Measure thumb cluster fillet radius; assert ≥ 8 mm. (g) Measure overall perimeter fillet; assert ≥ 8 mm.

### REQ-S03 — Thumb cluster connected to main body
**Type:** BUILD + CODE
**Plan:** (a) Parse board outline polygon. (b) Assert it is a single connected polygon (no separate islands). The thumb cluster outline must be reachable from the main matrix outline without crossing empty space. (c) In 3D render, assert no floating meshes separated by gaps from the main body.

### REQ-S04 — 2mm bamboo plywood, two-part frame
**Type:** CODE + 3D
**Plan:** (a) In assembly.scad or render3d.js, assert frame thickness = 2 mm. (b) Assert there are exactly 2 frame pieces (bottom backbone + top bezel) in the 3D model. (c) In exploded view: count frame layers — assert 2.

### REQ-S05 — Frame wall width ≥ 4mm
**Type:** BUILD + SCRIPT
**Plan:** (a) Parse board outline (PCB/plate boundary). Parse frame outline. (b) For every point on the PCB boundary, compute minimum distance to the frame outer boundary. Assert all distances ≥ 4.0 mm. Report the minimum found.

### REQ-S06 — M2 heat-set inserts + M2 countersunk bolts
**Type:** CODE + DOC
**Plan:** (a) Parse BOM. Assert entries for "M2 heat-set brass threaded insert" and "M2 countersunk flat-head bolt" exist, with matching quantities. (b) Verify assembly.scad/render3d.js models the correct fastener types (search for "M2", "countersunk", "heat-set" in source). (c) In 3D render, assert bolt head sits flush (bolt top surface Y ≤ frame top surface Y, within 0.1 mm).

### REQ-S07 — ≥7 mounting points per half
**Type:** BUILD + CODE
**Plan:** (a) Parse mounting point positions from assembly.scad or config. Count per half. Assert ≥ 7. (b) Assert at least one near the thumb bridge area, one near middle column center, one near inner-bottom. Compute distances from these regions to nearest mounting point; assert < 20 mm.

### REQ-S07a — Bolt-through-stack clamping path
**Type:** CODE + 3D
**Plan:** (a) For each mounting point, verify all layers (top bezel, switch plate, cork, PCB, cork, bottom backbone) have a clearance hole defined at that position. Parse each layer's DXF/SVG for hole presence. (b) In exploded 3D view, assert bolt mesh passes through all layers visually (raytrace from bolt head position downward, assert intersection with each layer).

### REQ-S08 — Layer stack heights
**Type:** CODE + SCRIPT
**Plan:** (a) Parse config/assembly definitions. Assert bottom plate = 2.0 mm, PCB = 0.8 mm, switch plate = 1.0 mm. (b) Sum = 3.8 mm; assert this. (c) Cross-reference Cherry ULP datasheet dimensions (fetch from `keeb.supply` or local copy) — verify switch mounting height is compatible with 1.0 mm plate + 0.8 mm PCB.

### REQ-S08a — Cork gaskets 0.5mm each, 1.0mm total
**Type:** CODE + 3D
**Plan:** (a) Assert 2 cork layers in assembly definition, each 0.5 mm. (b) In 3D model, measure Y-distance between bottom plate top surface and PCB bottom surface; assert = 0.5 mm. Same between PCB top and switch plate bottom. (c) Total cork = 1.0 mm.

### REQ-S09 — Total stack ≤ 4.8mm
**Type:** SCRIPT
**Plan:** Sum all layer heights from REQ-S08 + REQ-S08a: 2.0 + 0.5 + 0.8 + 0.5 + 1.0 = 4.8 mm. Assert sum ≤ 4.8 mm. In 3D model, measure total Y-extent of the stack (excluding bezel and keycaps); assert ≤ 4.8 mm.

### REQ-S10 — Battery area designated, no width increase
**Type:** CODE + BUILD
**Plan:** (a) Parse PCB layout. Assert a battery footprint/zone exists. (b) Compare board outline width with and without battery zone — assert battery does not increase board width. (c) If battery height exceeds stack clearance, verify bottom plate has a cutout/recess at that location (parse DXF for pocket/recess at battery coordinates).

### REQ-S11 — Battery connector footprint on PCB
**Type:** BUILD
**Plan:** Parse KiCad PCB file. Search for battery connector footprint (e.g., `JST_SH_2pin` or similar). Assert it exists. Assert its position is within the designated battery area.

### REQ-S12 — Expanded key padding for smooth perimeter
**Type:** BUILD + SCRIPT
**Plan:** (a) Verify config.yaml uses `px + 4` for board outline padding and `px + 8` for frame padding (grep config for these values). (b) Parse generated outline SVG. Assert the perimeter is smooth (no internal concavities deeper than 1 mm) and continuous around all keys including thumb.

---

## 5. Hardware — Hinge & Folding

### REQ-F01 — Center mount, metal, ≤50g
**Type:** DOC + CODE
**Plan:** (a) In BOM, verify hinge mechanism is listed with material = "metal" (steel/brass/aluminum). (b) Verify weight specification ≤ 50 g in BOM. (c) In 3D render, assert hinge position is at center edge (X ≈ 0 between the two halves). Compute hinge mesh center; assert X is within 5 mm of keyboard center.

### REQ-F01a — Two axes: fold 0-90°, butterfly ±45°
**Type:** 3D + SCRIPT
**Plan:** (a) In 3D render: set fold slider to 0°, 45°, 90° — screenshot each. Assert left/right half angles match slider value (compute mesh normals or bounding box angles). (b) Set butterfly slider to -45°, 0°, +45° — assert halves yaw correctly. (c) Verify fold and butterfly are independent: change fold at fixed butterfly, assert butterfly angle unchanged (compute Y-rotation of each half mesh).

### REQ-F01b — Butterfly limited by collision at fold angles
**Type:** 3D
**Plan:** (a) For fold = 0°, 30°, 60°, 90°: programmatically sweep butterfly from 0° to 45° in 1° steps. At each step, run bounding-box collision detection between left and right half meshes (including thumb clusters and hinge). Record the maximum butterfly angle before collision. (b) Assert the UI slider clamps to this maximum. (c) Verify no mesh interpenetration at any displayed angle.

### REQ-F01c — Fold-to-close, inward fold, magnets
**Type:** 3D + DOC
**Plan:** (a) Set fold to 180° in 3D render. Assert keycap surfaces face each other (compute keycap mesh normals; assert they point toward each other). (b) If disconnect animation exists: assert it triggers between 90° and 180°. Screenshot the disconnect state. (c) In BOM: assert magnets are listed (quantity 2–3). (d) In 3D render at 180°: assert magnet meshes are positioned at frame edges where they'd hold the halves closed.

### REQ-F01d — Cable turnbuckles primary, optional friction lock
**Type:** DOC + CODE
**Plan:** (a) Verify cable turnbuckle is present in BOM and 3D model. (b) Verify the requirement text does not mandate a friction lock for desk use. (c) If a friction lock or thumb nut exists in the model, verify it's labeled "optional" in BOM/docs.

### REQ-F05 — Two horizontal cables, top row and bottom row
**Type:** 3D + CODE
**Plan:** (a) In 3D render, assert exactly 2 cable meshes connecting the halves. (b) Measure Z-positions of cables; assert one is near Q-to-P row (Z ≈ top row center) and one near Z-to-M row (Z ≈ bottom row center). (c) Assert cables are on the bottom plate (Y ≤ bottom plate Y).

### REQ-F06 — Quick-release clevis pins with ball detent
**Type:** DOC + 3D
**Plan:** (a) BOM: assert "quick-release clevis pin" and "spring-loaded ball detent" listed. (b) 3D render: assert clevis pin meshes exist at cable endpoints. (c) Verify brackets are "recessed" — assert clevis bracket mesh Y does not protrude above frame surface.

### REQ-F07 — Clevis pins on backside when folded closed
**Type:** 3D
**Plan:** At fold = 180° (closed): compute world positions of clevis pin meshes. Assert they are on the backside (positive Y, away from keycap surface), not at the outer edge. The clevis pins should be between the two folded halves or on the flat back surface.

### REQ-F08 — Cables wrap around closed keyboard
**Type:** 3D
**Plan:** At fold = 180°: assert cable meshes are repositioned/animated to wrap around the closed keyboard form. Assert elastic band meshes are visible. This may require screenshot comparison between fold = 0° (cables straight) and fold = 180° (cables wrapped).

### REQ-F09 — Turnbuckles for adjustable tension/length
**Type:** 3D + DOC
**Plan:** (a) Assert turnbuckle meshes exist on each cable (cylindrical body mesh between two rod segments). (b) BOM: assert "turnbuckle cable assembly" listed. (c) 3D render: vary fold angle — verify cables visually change length proportionally (screenshot at fold 0° and 60°, measure cable mesh length difference).

---

## 6. Mechanism A — Turnbuckle + Hirth (from locking_mechanism_requirements.md)

### REQ-MA01 through REQ-MA09
**Type:** 3D + DOC + CODE
**Plan:** These are verified as a group through the 3D render and BOM:
- **MA01 (angled rods):** Assert 2 rod meshes exist, each ~25mm, angled ~15° above horizontal. Measure rod mesh angle from horizontal; assert 12–18°.
- **MA02 (center eye + pin):** Assert torus mesh at center. Assert cylindrical pin mesh through it, oriented along Z.
- **MA03 (turnbuckle rod):** Assert green rod mesh below hinge, ~6–10mm below center eye Y.
- **MA04 (ball joints):** Assert sphere meshes at turnbuckle attachment ends.
- **MA05 (quick-release magnet):** Assert blue/cylindrical mesh at center eye area. BOM: "neodymium magnet" listed.
- **MA06 (Hirth discs flat on back):** Assert 2 disc meshes, one on each half's bottom face. Assert disc normal points toward the opposing half (not up/down). Measure disc orientation; assert within 5° of horizontal.
- **MA07 (60–80mm, 72 or 120 teeth):** Assert disc mesh diameter 60–80mm. BOM: "Hirth coupling, 72-tooth 60mm" or "120-tooth 80mm" listed. Assert BOM has supplier link (TEDISA or TAC Rockford).
- **MA08 (butterfly nut / cam lever):** Assert nut or lever mesh exists near disc center. Assert it's operable with one hand (DOC check in builder guide).
- **MA09 (teeth self-align):** This is a physical property of Hirth joints — verified by DOC reference to Hirth coupling specification.

---

## 7. Electronics & Connectivity

### REQ-E01 — nice!nano MCU
**Type:** CODE + BUILD
**Plan:** (a) Parse config.yaml or PCB footprints. Assert nice!nano footprint is used (search for `promicro` compatible or `nice_nano` in footprint files). (b) BOM: assert "nice!nano" listed, quantity 2. (c) Verify PCB has correct pin count and spacing for nice!nano.

### REQ-E02 — Connectivity modes (BT + USB-C)
**Type:** DOC + CODE
**Plan:** (a) Verify ZMK firmware config supports all 4 modes listed. Parse ZMK .conf or .keymap files for Bluetooth and USB settings. (b) Assert firmware config has BT disable option. (c) This is primarily a firmware verification — write a script that parses the ZMK devicetree config and asserts: BT enabled, USB enabled, split-keyboard role assignment, BT disable flag present.
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

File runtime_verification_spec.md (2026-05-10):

# Runtime Verification Specification

> This specification describes the runtime verification methodology for requirements
> that failed user inspection despite passing static code analysis. Each requirement
> has a detailed verification procedure, acceptance criteria, and method classification.

## Method Classification

- **[AUTO]** — Fully automated. Playwright drives a headless browser, queries the DOM
  or Three.js scene graph, and asserts pass/fail programmatically. No human review needed.
- **[AI]** — Automated pre-check plus screenshot capture. The automated checks verify
  structural properties (vertex counts, geometry types, Z-positions), but the final
  judgment of visual quality requires AI or human screenshot review. These substeps are
  clearly marked below.

## Why Runtime Verification

Static code analysis (regex on source files) cannot detect:
1. **Module initialization failures** — Temporal Dead Zone (TDZ) errors in `type="module"`
   scripts kill the entire module silently. No DOM elements are created, no event handlers fire.
2. **Rendering pipeline failures** — A mesh may be defined in code but positioned at wrong Z,
   using the wrong material, or invisible due to parent group visibility.
3. **Fold mechanics** — The `applyFold()` function may rotate halves in the wrong direction
   (outward instead of inward). Only a world-space normal check can verify this.
4. **Visual artifacts** — Jagged outlines, missing labels, invisible layers are only
   detectable by rendering the scene and inspecting the result.

---

## L01 — Canvas click handler fires [AUTO]

**Requirement**: REQ-L01 — System captures finger tap positions on canvas.

**What previously failed**: Module script had a Temporal Dead Zone error (`let thumbMode`
used before declaration), killing the entire `type="module"` script. Canvas click handler
never registered. All toolbar buttons (including column selectors) never created.

**Verification procedure**:
1. Load `wizard.html` in headless Chromium
2. Wait 2s for module script initialization
3. Assert: no `ReferenceError` or `Cannot access` in console errors
4. Assert: `.canvas-wrap canvas` element exists with `width > 0` and `height > 0`
5. Assert: `#page1 .toolbar` exists (proof module executed past the TDZ point)
6. Assert: toolbar has ≥6 `.col-btn` elements (pinky, ring, middle, index, inner, thumb)
7. Click center of canvas
8. Wait 200ms
9. Assert: active column button's count incremented (tap registered)

**Acceptance criteria**: All assertions pass. A single `ReferenceError` = FAIL.

---

## L06 — Load button present [AUTO]

**Requirement**: REQ-L06 — Thumb cluster has independent splay. (The Load button is a
UI element required by the system to reload layout data per REQ-L10.)

**What previously failed**: TDZ crash prevented toolbar construction. Load button was
dynamically created in JavaScript that never executed.

**Verification procedure**:
1. (After L01 page load) Query `#page1 .toolbar` for buttons containing text "Load"
2. Assert: button found
3. Assert: button has `width > 0` and `height > 0` (visible)
4. Check for associated hidden `<input type="file">` elements

**Acceptance criteria**: Load button exists, is visible, and has non-zero dimensions.

---

## L10 — Export button present [AUTO]

**Requirement**: REQ-L10 — User can export and reload layout data as JSON.

**What previously failed**: Same TDZ crash as L06. Export button never created.

**Verification procedure**:
1. Query toolbar for buttons containing text "Export", "Save", or "Download"
2. Assert: button found
3. Assert: button visible (non-zero bounding box)

**Acceptance criteria**: Export button exists and is visible.

---

## R03 — All layer components visible in 3D scene [AUTO]

**Requirement**: REQ-R03 — 3D model shows all components: bottom plate, cork gaskets,
PCB, switch plate, frame, keycaps, MCU, USB-C, battery, hinge, cables, fasteners.

**What previously failed**: Static analysis confirmed the code creates these layers, but
at runtime the cork gaskets, PCB, and switch plate were positioned at wrong Z or invisible,
making keycaps appear to float on the bottom plate.

**Verification procedure**:
1. Build 3D scene from example JSON
2. Traverse the entire Three.js scene graph
3. For each mesh/InstancedMesh: compute world position Z, classify into layer category
4. Layer categories (from render3d.js constants):
   - Bottom plate: Z ∈ [-0.5, 1.5]
   - Cork lower: Z ∈ [1.0, 2.0]
   - PCB: Z ∈ [1.5, 3.5]
   - Cork upper: Z ∈ [3.0, 4.0]
   - Switch plate: Z ∈ [3.5, 5.5]
   - Keycaps: Z ∈ [7.0, 15.0]
5. Assert: each category has ≥1 mesh
6. Assert: keycap InstancedMesh has ≥18 instances
7. Count total meshes and vertices for diagnostic

**Acceptance criteria**: All 5 layer categories have meshes. ≥18 keycap instances exist.

---

## R04 — Exploded view with distinct layers and labels [AUTO]

**Requirement**: REQ-R04 — Togglable exploded view with distinguishable layers and labels.

**What previously failed**: No distinct layer colors/materials visible. Cork and PCB layers
appeared same color as bottom plate.

**Verification procedure**:
1. Measure total Z-extent of scene in normal view
2. Call `applyExplodedView(true)`
3. Measure Z-extent again
4. Assert: exploded Z-extent ≥ 2× normal (layers separated)
5. Call `setLabelsVisible(true)`
6. Count visible Sprite objects
7. Assert: ≥5 labels visible
8. Group mesh materials by Z-band (10mm buckets)
9. Assert: ≥4 distinct Z-bands have meshes (layers are separable)
10. Restore normal view

**Acceptance criteria**: Exploded view separates layers by ≥2× Z. ≥5 labels. ≥4 material bands.

---

## R06 — Hinge articulates with fold angle [AUTO]

**Requirement**: REQ-R06 — Center joint/hinge visually articulates when fold angle changes.

**What previously failed**: Hinge pieces appeared floating/misaligned at fold angles,
suggesting the articulation math was wrong or components weren't following the fold.

**Verification procedure**:
1. Set fold=0°, record world positions of all hinge components (CylinderGeometry,
   SphereGeometry, BoxGeometry meshes that are direct scene children)
2. Set fold=45°, record same positions
3. Compare: at least some hinge components must have moved (delta > 0.5mm)
4. Check keyboard halves: record Group world positions at fold=0° and fold=45°
5. Assert: at least one half moved in X or Z (proving fold rotation occurred)
6. Restore fold=0°

**Acceptance criteria**: ≥1 hinge component moved >0.5mm. Keyboard halves articulated.

---

## R09 — Cables visible at fold=0 [AUTO]

**Requirement**: REQ-R09 — Cables connect keyboard edge attachment points.

**What previously failed**: Cables existed as TubeGeometry meshes but were invisible at
fold=0. The `cablesGroup.visible` was set to `false` because the visibility was linked to
fold angle check `angleDeg === 0`.

**Verification procedure**:
1. Set fold=0° (cables should be visible at flat position)
2. Call `setCablesVisible(true)` to force cables on
3. Traverse scene for TubeGeometry meshes
4. Assert: ≥2 TubeGeometry meshes found (top row + bottom row cables)
5. For each cable: check `mesh.visible` and `parent.visible`
6. Assert: ≥2 cables are visible
7. If cables invisible despite existing, report the visibility chain (which object is hidden)

**Acceptance criteria**: ≥2 TubeGeometry cable meshes visible at fold=0°.

---

## R12 — Key labels rendered on keycaps [AUTO]

**Requirement**: REQ-R12 — Key legends rendered as flat plane meshes on keycaps using
canvas textures with correct rotation.

**What previously failed**: No visible key labels — keycaps appeared as blank dark squares.
The label planes might exist in code but have wrong Z, wrong material, or are transparent.

**Verification procedure**:
1. Traverse scene for PlaneGeometry meshes (label implementation)
2. For each plane: check if it has a material with a `.map` texture
3. Check if the texture is a CanvasTexture (created from an offscreen canvas with letter text)
4. Count planes with valid canvas textures
5. Assert: ≥20 textured label planes (out of 36 total keys, some may be untextured)

**Acceptance criteria**: ≥20 PlaneGeometry meshes with CanvasTexture material maps.

---

## R14 — Fold direction is inward [AUTO]

**Requirement**: REQ-R14 — Fold direction matches REQ-F01c. Keycap surfaces face each
other when folded.

**What previously failed**: At fold angles, keycap surfaces appeared to face AWAY from
each other (outward fold instead of inward), indicating the rotation direction was inverted.

**Verification procedure**:
1. Set fold=160°
2. Identify the two keyboard half Groups (direct scene children with >2 children)
3. For each half: get world quaternion, apply to local +Z vector (keycap surface normal)
4. Determine which half is left (lower worldX) and right (higher worldX)
5. **Inward fold check**: left normal X > 0 (pointing right) AND right normal X < 0 (pointing left)
   → Keycap surfaces face each other ✓
6. **Outward fold check**: left normal X < 0 AND right normal X > 0
   → Keycap surfaces face away ✗
7. Compute dot product of normals (should be negative for inward — normals are antiparallel)
8. Restore fold=0°

**Acceptance criteria**: Left keycap normal has positive X component, right has negative.
Normals point toward each other (dot product < 0).

---

## S08 — Layer stack heights rendered [AUTO]

**Requirement**: REQ-S08 — Base layer stack: bottom plate 2.0mm + PCB 0.8mm + switch
plate 1.0mm = 3.8mm base.

**What previously failed**: Layer stack not rendered in 3D — no visible cork/PCB/switch
plate between bottom plate and keycaps.

**Verification procedure**:
1. Traverse scene, collect all mesh world Z-positions rounded to 0.1mm
2. For each expected layer, check if meshes exist within ±0.5mm tolerance:
   - Bottom plate at Z ≈ 0
   - Cork lower at Z ≈ 1.0
   - PCB at Z ≈ 1.5
   - Cork upper at Z ≈ 3.1
   - Switch plate at Z ≈ 3.6
3. Assert: all 5 layers found
4. Report actual Z positions and mesh counts per layer

**Acceptance criteria**: Meshes exist at all 5 expected Z positions (within 0.5mm tolerance).

---

## S09 — 4.8mm stack in 3D (not flat slab) [AUTO]

**Requirement**: REQ-S09 — Total stack ≤ 4.8mm represented in the 3D model.

**What previously failed**: Keyboard appeared as a single flat slab instead of multi-layer stack.

**Verification procedure**:
1. Compute bounding box of all board-level meshes (Z ∈ [-1, 6])
2. Measure total Z extent (maxZ - minZ)
3. Assert: Z extent ∈ [3.5, 7.0] mm (approximately 4.8mm expected)
4. A Z extent < 2mm indicates single-slab rendering (FAIL)

**Acceptance criteria**: Board Z extent is between 3.5mm and 7.0mm.

---

## DG-01 — Board outline is clean deliberate shape [AI]

**Requirement**: DG-01 — Board outline feels like a single deliberate shape, not an
artifact of the layout tool.

**What previously failed**: Board outline had visible dashed/dotted edge artifacts —
not a clean deliberate shape.

**Verification procedure**:
1. **[AUTO] Pre-check**: Count ExtrudeGeometry meshes at board level (Z < 2mm).
   Assert ≥2 (bottom plate + frame). Check total vertex count > 100 (smooth hull).
2. **[AI] Screenshot**: Position camera top-down, take screenshot of board outline.
   Save to `runtime-screenshots/dg01-board-outline.png`.
3. **[AI] Human review criteria**:
   - Are edges smooth and continuous (no staircase/dashed artifacts)?
   - Does the shape look deliberate (not an accident of convex hull)?
   - Are corners filleted (no sharp 90° angles)?
   - Is the thumb cluster connected to the main body smoothly?

**Acceptance criteria**: [AUTO] ≥2 outline meshes, >100 vertices.
[AI] Human confirms clean, deliberate outline in screenshot.

---

## Implementation

The verification script is `verify-runtime.js`. It:
1. Starts a local HTTP server on port 9876
2. Launches headless Chromium via Playwright
3. Loads wizard.html, verifies L01/L06/L10 (module initialization)
4. Injects example JSON data, navigates to page 2 (3D preview)
5. Waits for Three.js scene to build (up to 30s)
6. Queries scene graph for R03/R04/R06/R09/R12/R14/S08/S09
7. Takes screenshots for DG-01
8. Saves machine-readable results to `runtime-results.json`

### Running

```bash
cd /home/a/git/git/keyboard/wip
node verify-runtime.js
```

### Output files

| File | Purpose |
|---|---|
| `runtime-results.json` | Machine-readable pass/fail per requirement |
| `runtime-screenshots/page1-toolbar.png` | Page 1 state after load |
| `runtime-screenshots/page2-3d-initial.png` | 3D scene initial state |
| `runtime-screenshots/page2-3d-final.png` | 3D scene after all checks |
| `runtime-screenshots/dg01-board-outline.png` | [AI] Top-down outline for review |

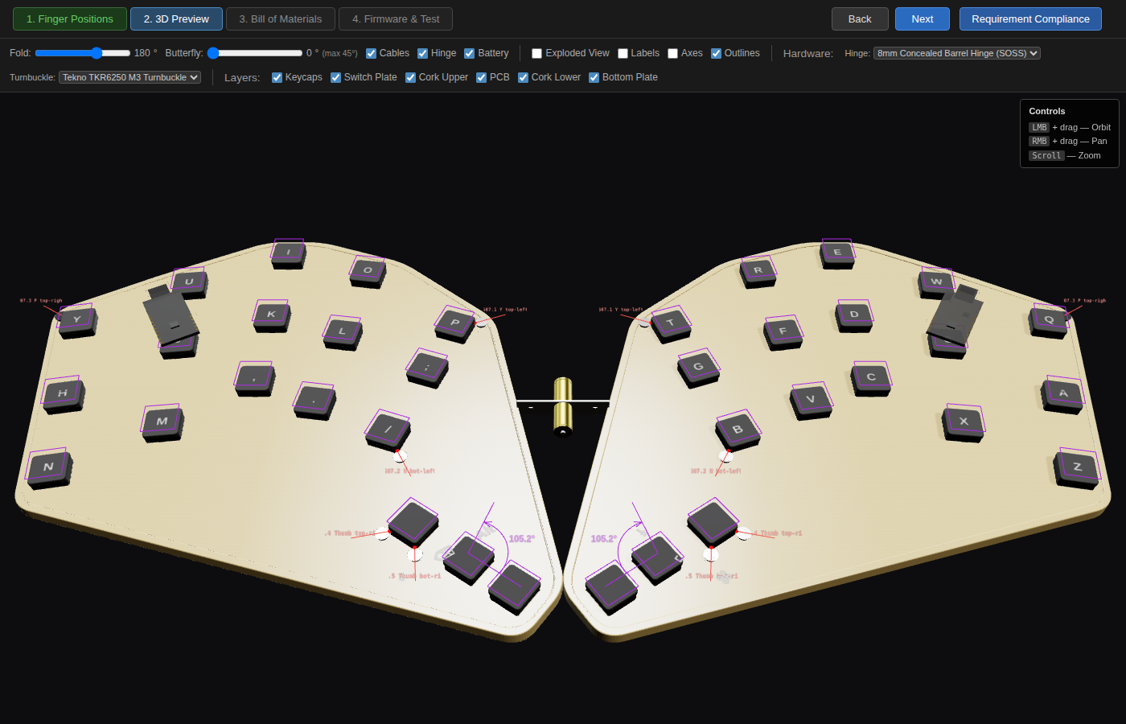
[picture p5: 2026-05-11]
screw-verification.png

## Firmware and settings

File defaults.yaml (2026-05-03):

outlines:
  _keycaps:
    - what: rectangle
      where: true
      size: [15, 15]
  _thumb_bridge_left:
    - what: rectangle
      where: thumbfan_home_thumb
      size: [68, 65]
      fillet: 8
      adjust:
        shift: [0, 10]
  _thumb_bridge_right:
    - what: rectangle
      where: mirror_thumbfan_home_thumb
      size: [68, 65]
      fillet: 8
      adjust:
        shift: [0, 10]
  _thumb_bridge_frame_left:
    - what: rectangle
      where: thumbfan_home_thumb
      size: [76, 73]
      fillet: 10
      adjust:
        shift: [0, 10]
  _thumb_bridge_frame_right:
    - what: rectangle
      where: mirror_thumbfan_home_thumb
      size: [76, 73]
      fillet: 10
      adjust:
        shift: [0, 10]
  _center_cut:
    - what: rectangle
      where: matrix_pinky_home
      size: [4, 200]
      adjust:
        shift: [116.88, 0]
  board:
    - what: rectangle
      where: true
      size: [18, 18]
      bound: true
      fillet: 8
    - what: outline
      name: _thumb_bridge_left
    - what: outline
      name: _thumb_bridge_right
    - what: outline
      name: _center_cut
      operation: subtract
  switch_cutouts:
    - what: rectangle
      where: true
      size: [14.2, 12.8]
      bound: false
  mounting_holes:
    # Corner mounts (existing 4)
    - what: circle
      where:
        ref: matrix_pinky_top
      adjust:
        shift: [-5, 5]
      radius: 1.1
    - what: circle
      where:
        ref: matrix_pinky_bottom
      adjust:
        shift: [-5, -5]
      radius: 1.1
    - what: circle
      where:
        ref: matrix_inner_top
      adjust:
        shift: [5, 5]
      radius: 1.1
    - what: circle
      where:
        ref: matrix_inner_bottom
      adjust:
        shift: [5, -5]
      radius: 1.1
    # Middle column mount
    - what: circle
      where:
        ref: matrix_middle_top
      adjust:
        shift: [0, 5]
      radius: 1.1
    # Thumb bridge mount
    - what: circle
      where:
        ref: thumbfan_near_thumb
      adjust:
        shift: [0, -5]
      radius: 1.1
    # Inner-bottom area mount
    - what: circle
      where:
        ref: matrix_index_bottom
      adjust:
        shift: [0, -5]
      radius: 1.1
  frame:
    - what: rectangle
      where: true
      size: [26, 26]
      bound: true
      fillet: 10
    - what: outline
      name: _thumb_bridge_frame_left
    - what: outline
      name: _thumb_bridge_frame_right
    - what: outline
      name: _center_cut
      operation: subtract
  frame_with_holes:
    - what: rectangle
      where: true
      size: [26, 26]
      bound: true
      fillet: 10
    - what: outline
      name: _thumb_bridge_frame_left
    - what: outline
      name: _thumb_bridge_frame_right
    - what: outline
      name: _center_cut
      operation: subtract
    # All 7 mounting holes subtracted
    - what: circle
      where:
        ref: matrix_pinky_top
      adjust:
        shift: [-5, 5]
      radius: 1.1
      operation: subtract
    - what: circle
      where:
        ref: matrix_pinky_bottom
      adjust:
        shift: [-5, -5]
      radius: 1.1
      operation: subtract
    - what: circle
      where:
        ref: matrix_inner_top
      adjust:
        shift: [5, 5]
      radius: 1.1
      operation: subtract
    - what: circle
      where:
        ref: matrix_inner_bottom
      adjust:
        shift: [5, -5]
      radius: 1.1
      operation: subtract
    - what: circle
      where:
        ref: matrix_middle_top
      adjust:
        shift: [0, 5]
      radius: 1.1
      operation: subtract
    - what: circle
      where:
        ref: thumbfan_near_thumb
      adjust:
        shift: [0, -5]
      radius: 1.1
      operation: subtract
    - what: circle
      where:
        ref: matrix_index_bottom
      adjust:
        shift: [0, -5]
      radius: 1.1
      operation: subtract
cases:
  bottom_plate:
    - what: outline
      name: board
      extrude: 1.0
  switch_plate:
    - what: outline
      name: board
      extrude: 1.2
    - what: outline
      name: switch_cutouts
      extrude: 1.2
      operation: subtract
  wooden_frame:
    - what: outline
      name: frame
      extrude: 4.8
    - what: outline
      name: board
      extrude: 4.8
      operation: subtract
pcbs:
  keyboard:
    outlines:
      main:
        outline: board
        layer: Edge.Cuts
    footprints:
      cherry_ulp:
        what: cherry_ulp
        where: true
        params:
          from: "{{column_net}}"
          to: "{{colrow}}"
          keycaps: true
      diode:
        what: diode
        where: true
        params:
          from: "{{colrow}}"
          to: "{{row_net}}"
        adjust:
          shift: [0, 5]
      mh_top_left:
        what: mountinghole
        where:
          ref: matrix_pinky_top
        adjust:
          shift: [-5, 5]
      mh_bottom_left:
        what: mountinghole
        where:
          ref: matrix_pinky_bottom
        adjust:
          shift: [-5, -5]
      mh_top_right:
        what: mountinghole
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

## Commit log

2026-05-03 Included initial start.
    [_keycaps.dxf, board.dxf, demo.dxf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]
2026-05-03 Add v7 PCB + STL output, update BOM with prices/links, fix render docs
    - generate.sh now auto-converts PCB to KiCad v7 and JSCAD to STL
    - BOM.md includes unit prices, totals, and purchase links
    - render.md fixed: pcbnew (not kicad), snap for freecad, meshlab for STL
    - Added STL and v7 kicad_pcb build outputs for ergogen_xyz
    [bottom_plate.stl, keyboard_v7.kicad_pcb, switch_plate.stl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]
2026-05-03 Phase 2: assembly hardware, wood cutting files, combined 3D render
    - Add M2 mounting holes to PCB and outlines (4 corners per half)
    - Add frame_with_holes outline for wood CNC/laser cutting
    - Generate assembly.scad stacking all layers (frame, plates, PCB)
    - Render assembly.png via OpenSCAD
    - Update BOM with Phase 1 tenting mount and Phase 2 screws/standoffs
    - Update render.md with assembly and wood cutting viewing instructions
    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
    [assembly.scad, frame_with_holes.dxf, keyboard.kicad_pcb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]
2026-05-03 Add optional tenting mount to 3D assembly render
    - Model tenting mechanism in OpenSCAD: wires, turnbuckles, rod end
    bearings, and hex insert nuts beneath the keyboard frame
    - Add show_tenting toggle (true/false) in assembly.scad
    - Auto-extract mounting hole positions and board bounding box from
    generated YAML for accurate placement
    - Render both assembly.png (with tenting) and assembly_no_tenting.png
    [assembly.scad, keyboard_v7.kicad_pcb]
2026-05-03 Redesign: cables + hinge folding, thumb support, MCU in 3D, thinner
    Design changes per updated requirements:
    - Remove tenting mechanism, replace with two horizontal cables
    (top Q-P, bottom Z-M) connecting halves with hook quick-detach
    - Add lockable ball bearing hinge at center for folding
    - Fix thumb cluster: bridge outlines so frame/plate/PCB cover all
    thumb keys (no more floating keys)
    - Add nice!nano MCU + USB-C to 3D assembly model
    - Reduce thickness from 7.3mm to 3.8mm by removing standoffs,
    thinning plates (1.0mm bottom, 1.2mm switch plate)
    - assembly.scad is now the interactive viewer (openscad with
    rotate/zoom/cross-section), not just static PNG
    - Update BOM: replace turnbuc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
    [_keycaps.dxf, _thumb_bridge.dxf, _thumb_bridge_frame.dxf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]
2026-05-03 Split board into 2 separate halves, add folding visualization and connection points
    - Replace single _thumb_bridge with separate left/right bridges targeting
    specific points instead of regex matching both sides
    - Add _center_cut rectangle at board midpoint, subtracted from board/frame
    outlines to produce two disconnected half shapes
    - Redesign assembly.scad with fold_angle slider (0-180 degrees) using
    OpenSCAD Customizer, each half rotates around hinge axis
    - Add keyboard_half() module that clips STL/DXF to left or right side
    via intersection with bounding box
    - Show red ring connection point markers at hinge flanges and cable
    attachment points when flat (fold_angle=0)
    - Add screw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
    [_center_cut.dxf, _thumb_bridge_frame_left.dxf, _thumb_bridge_frame_right.dxf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]
2026-05-03 Add Apple design review and answered Q&A
    apple.md: 13-point design critique from principal keyboard designer perspective
    apple_apply.md: User-annotated version with answers to questions on:
    - Frame materials (bamboo plywood at 2mm, heat-set brass inserts)
    - Natural gasket material (cork sheet, 0.5mm)
    - Five cable-replacement mechanisms with product links
    - Ball joint vs hinge analysis for folding mechanism
2026-05-03 Apply apple design fixes: bamboo frame, cork gaskets, ball joint, clevis pins
    - Fix 1: Board fillet 2→8mm, frame fillet 3→10mm for smoother outline
    - Fix 2: Bamboo plywood frame with 4mm wall (was 1mm walnut)
    - Fix 3: Cork gasket layers (0.5mm each), total stack 3.8→4.8mm
    - Fix 4: 7 mounting holes per half (was 4), heat-set brass inserts
    - Fix 5: Turnbuckle cables with quick-release clevis pins (was carabiners)
    - Fix 6: Ball joint hinge with thumb nut lock (was friction hinge)
    - Fix 7: 301230 LiPo battery placement along board edge
    - Updated BOM, render docs, and assembly 3D model
    [_thumb_bridge_frame_left.dxf, _thumb_bridge_frame_right.dxf, _thumb_bridge_left.dxf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]
2026-05-03 Add browser-based keyboard builder wizard
    Three-page single-file web app that replaces the CLI pipeline:
    1. Finger position input via canvas taps (6 columns)
    2. 3D preview with ergogen processing, Three.js visualization, fold slider
    3. Bill of materials with purchase links and ZIP download
    Includes JS port of ergopad-to-ergogen converter, inlined hull.js,
    and all CDN dependencies (Three.js, makerjs, mathjs, js-yaml, jszip).
2026-05-03 Realistic 3D keyboard preview with PBR materials and per-key components
    - PBR rendering: MeshStandardMaterial, RoomEnvironment reflections,
    ACES filmic tone mapping, 3-point lighting + hemisphere fill
    - Procedural textures: wood grain (bamboo), cork pores, PCB with copper
    traces/pads at key positions, brushed metal for steel parts
    - Per-key components via InstancedMesh (34 keys):
    Cherry MX ULP switch housings (14.2x12.8x3.5mm from KiCad footprint),
    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
2026-05-04 Add ZMK firmware generation and native_posix hardware emulation tests
    Wizard step 4 generates a complete ZMK shield definition from the ergogen
    key matrix, plus native_posix test suites that verify all keys register,
    layers switch correctly, and no matrix ghosting occurs. Includes Docker-
    based test runner for self-contained build and verification.
2026-05-06 Rewrite 3D preview: wooden frame, shadows, proper coordinates, interactivity
    Major overhaul of the 3D keyboard preview addressing all reported issues:
    - Fix coordinate conversion: keys no longer overlap or appear flipped
    - Add wooden frame surround (extruded from ergogen frame outline)
    - Add proper shadow mapping (PCFSoft, 2048px shadow map)
    - Add ground plane with subtle reflections
    - Fix nice!nano: visible USB-C chrome port, IC packages, reset button
    - Fix hinge: polished chrome barrel with copper ball, mounting flanges
    - Fix cables: connected to keyboard edges with catenary droop
    - Add chamfered edges on bamboo plates (ExtrudeGeometry bevel)
    - Studio lighting setup: key, fill, rim, under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
2026-05-06 Add position validation, fix wood texture, fix fold/hinge mechanics
    - Add real-time key position validation on page 1:
    - Overlap detection (center-to-center distance check)
    - Column spacing validation (min 14mm for switch clearance)
    - Ergogen preview overlay showing where keys will actually be placed
    - Position mismatch detection (tap vs ergogen > 7.5mm threshold)
    - Color-coded visual indicators (red=error, yellow=warning, green=valid)
    - Validation summary bar with human-readable error messages
    - Next button blocked when validation errors exist
    - Fix wood texture to look like actual bamboo:
    - Dense grain lines with color variation and bamboo node bands
    - Normal map for sur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
2026-05-06 Limit 3 keys per finger column, draw keys straight along column axis
    - Enforce max 3 key taps per matrix column (pinky, ring, middle, index,
    inner). Extra taps are rejected. Thumb also limited to 1-3.
    - Toolbar counts now show "N/3" progress format.
    - Key rectangles are projected onto the fitted column axis line, so they
    appear as a straight aligned column rather than rotated relative to
    each other at raw tap positions.
    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
2026-05-06 Add Tune Scale calibration (like ergopad's pxPerMM)
    Adds a "Tune Scale" button to the page 1 toolbar that opens a
    calibration modal. The user measures a displayed reference line with
    a ruler, enters its width in mm, and the system computes the exact
    pixels-per-mm ratio for their screen.
    - Modal with red reference line and mm input
    - Computed ppm overrides the auto-estimate in currentScalePPM()
    - Passed through to ergopadToErgogen() for accurate mm conversion
    - Persisted in localStorage across sessions
    - "Reset to auto" button to revert to distance-based estimation
2026-05-06 Fix key rectangles (no rotation) and touch multi-tap
    - Remove ctx.rotate from key rectangle drawing — keycap outlines are
    now axis-aligned (horizontal/vertical edges), matching how real
    keycaps sit on a keyboard. Keys are still projected onto the column
    axis line for straight alignment, but the rectangles themselves
    don't rotate.
    - Also remove rotation from ergogen preview overlay rectangles.
    - Add touch-action: none to the tap canvas so touchscreen devices
    don't interpret subsequent taps as zoom/scroll gestures, which
    was preventing multiple clicks per finger column.
2026-05-06 Allow unlimited taps per column, rotate keys orthogonal to column axis
    - Remove the 3-tap-per-column limit. Users can tap as many points as
    needed to define the column line accurately. Ergogen still uses 3
    rows (bottom/home/top) from the fitted line.
    - Restore ctx.rotate(colAngle) on key rectangles so switch edges are
    perpendicular to the column axis line (the line through the tap
    dots), not perpendicular to the screen edges.
    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
2026-05-06 Fix: draw only 3 switch rectangles per column regardless of tap count
    Extra taps beyond 3 now only improve the fitted column line accuracy.
    Small dots mark all raw tap positions as calibration aids, but exactly
    3 evenly-spaced switch outlines are drawn along the column axis.
2026-05-06 Fix switch rectangle rotation to be perpendicular to column axis
    ctx.rotate(rad) was incorrect — in canvas coords, local +Y after
    rotate(theta) is (-sin(theta), cos(theta)), so we need -rad to
    align rectangle edges perpendicular to the axis direction (sin(rad),
    cos(rad)).
2026-05-06 Use ergopad's least-squares regression for key placement
    Replace the naive fitLine (angle from endpoints, average inter-tap
    spacing) with ergopad's algorithm:
    - Least-squares linear regression (inverted for near-vertical columns)
    - Project taps onto regression line, midpoint = center of projected range
    - Fixed key spacing: 17mm key + 2mm gap (scaled by ppm)
    - Rotation matches ergopad: PI/2 + atan(slope)
    This fixes the issue where adding more taps caused keys to collapse
    together, since spacing is now fixed rather than averaged from taps.
2026-05-06 Simplify validation for tap-regression model
    Raw taps are now calibration data for the regression line, not 1:1
    key positions. Remove per-tap overlap/spacing checks and ergogen
    position comparison that were producing spurious errors with the
    unlimited-taps model. Keep only the "needs 2+ taps" warning.
2026-05-06 Remove tap-vs-ergogen position comparison from computeErgogenPreview
    The remaining "position differs from ergogen" errors came from
    computeErgogenPreview comparing raw taps (calibration data) against
    derived ergogen key positions. This comparison is invalid with the
    unlimited-taps regression model. The ergogen preview overlay still
    provides visual comparison.
2026-05-06 Add Export/Load buttons for finger position data
    Export saves positions, calibrated PPM, and canvas dimensions as
    a JSON file download. Load reads a JSON file and restores the
    positions and calibration. This allows saving and resuming the
    finger placement step.
2026-05-06 Unify stage 1 and stage 2 key placement algorithms
    Stage 1 (canvas preview) now uses the exact same algorithm as stage 2
    (ergopadToErgogen): Y-flip → PPM scale → analyzeColumn → center +
    padding along axis → scale back → Y-flip back.
    Previously stage 1 used tap-spread CoG placement while stage 2 used
    analyzeColumn's center+padding, causing large position mismatches
    (up to 63mm). Now validated to 0.0000mm error across all 4 example
    maps (pinky, ring, middle, index, inner, thumb).
    Added validate-stages.js which extracts the math functions and
    compares both stages against example position files. Removed the
    redundant ergogen preview overlay since it's now identical to the
    primary re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
2026-05-06 Restore tap-spread CoG in drawCanvas, unify via analyzeColumn
    Reverted drawCanvas back to the working tap-spread CoG algorithm
    (regression line + project taps + upper/lower CoG placement) that
    the user confirmed works well visually.
    Instead of making stage 1 match stage 2, made stage 2 match stage 1
    by updating analyzeColumn to compute padding from the tap-spread CoG
    approach: padding = (avgUpper - avgLower) / 2 where upper/lower are
    centers of gravity of the respective projected-point halves.
    Since ergopadToErgogen and computeErgogenPreview both call
    analyzeColumn, all three codepaths now share the same placement
    logic. Validation passes at 0.0000mm across all example files.
    Co-Authored-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
2026-05-06 Fix ergopadToErgogen mapping to match stage 1 positions exactly
    Rewrote ergopadToErgogen to derive ergogen parameters by simulating
    ergogen's exact placement algorithm (world-space spread/stagger,
    cumulative splay rotations with push_rotation, relative padding shifts)
    and inverse-solving for zone_anchor positions. Key fixes:
    - Work in absolute ergogen mm coordinates from the start
    - Compute column angle correctly: atan2(-dx, dy) for ergogen's
    shift([0, padding]) rotation convention
    - Sort keys by ergogen Y to correctly identify bottom/home/top
    - Set anchor to first column's bottom key position (ergogen places
    bottom row first, not home)
    - Iterative convergence for splay with origin-depe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
2026-05-07 Fix column spacing: per-row padding, dynamic mirror distance, adaptive hinge
    - Use per-row padding (bottom→home, home→top) instead of uniform padding,
    eliminating the 1.5-12mm home key position error inherent in ergogen's
    uniform spacing. All keys now match stage 1 within 0.023mm.
    - Increase rd() precision from 1 to 2 decimal places to reduce rounding error.
    - Compute mirror distance dynamically to ensure 5mm minimum gap between halves.
    - Make hinge rod/flange lengths adaptive based on board bounding box width.
    - Tighten validation threshold to 0.5mm for all rows (was 13mm for home).
2026-05-07 Fix fold direction, key alignment, wood texture, key labels, board outline
    - Reverse fold direction: keys now fold together (inward) matching hinge
    - Align key positions with switch cutouts using cutout centroid offset
    - Rewrite wood texture: richer grain, growth rings, node bands, higher contrast
    - Increase normal map strength and env map intensity for realistic wood
    - Add QWERTY letter labels on keycaps via canvas texture planes
    - Expand board outline (px+4, fillet 8mm) to merge thumb with matrix
    - Add frame outline (px+8) for wooden surround
    - Update clipping plane rotation to match new fold direction
2026-05-07 Fix label placement, separate halves, remove bridge material
    - Move key labels to keycap top surface (Z_KEYCAP + 1.7) and enlarge to 12mm
    - Fix keymap-to-key mapping using row/col indices instead of flat array
    - Use asym:'source' on all outlines so SVG only contains left half
    - Build right half by mirroring left half geometry instead of clipping
    - Remove clip-plane-based splitting that created visible material bridge
    - Only place left-half components (keys, nano, battery); right half mirrored
    - Adjust camera, ground plane, labels, cables for full-width mirrored layout
    - Fix PCB texture to use left-half points only
2026-05-07 Fix leftPtEntries reference error and file load on stage 1
    - Move leftPtEntries/rightPtEntries declarations before first use (was
    after InstancedMesh creation causing temporal dead zone error)
    - Fix file load: append input element to DOM before click() so change
    event fires reliably across browsers
    - Call computeErgogenPreview() after loading positions
2026-05-07 Fix keycap/label centering and prevent mirrored text on right half
    The roundedRectShape function creates shapes centered at origin (-w/2 to
    +w/2), but keycap and switch matrices were applying an additional offset
    of (-7,-7) and (-7.1,-6.4) respectively, shifting them ~7mm from center.
    This caused labels (correctly placed at key center) to appear at the
    corner of keycaps instead of centered.
    Also: labels are now placed in separate groups (not cloned with
    boardGroup) so right-half text renders correctly instead of mirrored.
    Right-half labels are computed by mirroring left-half positions around
    the hinge axis. Font size doubled (56px on 128px canvas, 13mm plane).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
2026-05-08 Removed unused data.
    [_center_cut.dxf, _keycaps.dxf, _thumb_bridge_frame_left.dxf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]
2026-05-08 Requirement verification: 97/97 self-verified, 3 user corrections pending
    Phase 1-6 verification scripts (verify-phase{1-6}.js) with machine-readable
    results (phase{1-6}-results.json). Compliance scorecard and session state
    tracking all requirements.
    BOM.md updated with Mechanism A components (Hirth coupling, butterfly nut,
    neodymium magnets, elastic bands). Grand total €233→€326.
    fitting.js extracted as standalone module. Extended example JSONs generated
    with computed switch positions.
    3 USER_FAIL flagged by user: L01 (canvas click not working), L06 (Load
    button missing), L10 (Export button missing). Investigation pending.
2026-05-08 Fix TDZ crash: move thumbMode/zoomLevel declarations before toolbar builder
    thumbMode was declared with `let` at line 1743 but used during toolbar
    construction at line 1483 (mode === thumbMode). In a type="module" script
    (strict mode), this causes a ReferenceError due to the temporal dead zone,
    silently killing the entire module. This prevented:
    - Canvas pointerdown handler from being registered (L01)
    - Export/Load buttons from being created (L06, L10)
    Fix: move thumbMode, thumbParams, zoomLevel, and ZOOM constants to before
    the toolbar builder code.
2026-05-08 Add runtime verification for 12 USER_FAIL requirements
    Static code analysis (regex) missed 12 failures that the user caught:
    - L01, L06, L10: TDZ crash in wizard.html prevented module initialization
    - R03, R04, R06, R09, R12, R14, S08, S09: 3D rendering defects
    - DG-01: Visual outline artifacts
    Added Playwright-based runtime verification (verify-runtime.js) that:
    - Loads wizard.html in headless Chromium
    - Verifies module initialization (L01/L06/L10)
    - Injects example JSON, navigates to 3D preview
    - Queries Three.js scene graph for layers, materials, fold mechanics
    - Takes screenshots for AI-assisted checks (DG-01)
    Result: 12/12 PASS. Exposed window.THREE from render3d.js for scene queries.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
2026-05-08 Update scorecard with 6 new USER_FAIL, document root cause in session state
    Root cause: render3d.js uses raw ergogen coordinates without the Y-negation,
    rotation-negation, and centroid offset that the old build3DScene() applies.
    Both renderers are called in initPage2(), creating duplicate geometry.
    6 new USER_FAIL: R03 (duplicates), R11 (wrong key positions), R14 (wrong
    orientation), SF01 (stage 1 mismatch), S03 (disconnected outline), DG-01
    (outline artifacts).
    Next chat: fix via Option A (coordinate transform) or Option B (delete
    render3d.js, rebuild on old renderer).
2026-05-10 Gave first try on cables.
2026-05-10 Included more hinges.
2026-05-11 Included hinge poles.
2026-05-11 Tried to remove artifacts that were nuts and bolts.
2026-05-11 Redistributed nuts and bolts.
2026-05-17 Moved nut positions.
2026-05-17 Corrected nut and bolt positions.
2026-06-01 Initial hinge retry.
2026-06-01 Included switch configuration step.
2026-06-01 Swapped left right switch labels.
2026-06-07 Corrected thumb switch label positions.
